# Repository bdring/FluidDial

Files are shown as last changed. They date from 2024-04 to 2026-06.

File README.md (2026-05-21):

# FluidDial: A Wired/Wireless CNC Pendant for FluidNC Firmware.

M5 Fluid DialCYD Dial Pendant

Wiki pages for more information: [M5 FluidDial Pendant (left image)](http://wiki.fluidnc.com/en/hardware/official/M5Dial_Pendant) and [CYD Dial Pendant (right image)](http://wiki.fluidnc.com/en/hardware/official/CYD_Dial_Pendant).

Both have similar functionality and similar cost, using different hardware.

## Overview

FluidDial supports two connection modes — **WiFi** and **Wired (UART)** — and is fully compatible with both the **M5Dial** and **CYD** pendant hardware.

In WiFi mode the pendant communicates with FluidNC over WebSockets on your local network. In Wired mode it uses the physical UART serial connection. The active mode is persisted across reboots and can be switched at any time from the Connection Settings screen.

### Features
- **DRO** — real-time X/Y/Z work coordinate display with configurable decimal places
- **Homing** — single-axis or full-machine homing with per-axis status feedback
- **Jogging** — multi-axis jog with encoder control, configurable step size, and one-tap axis zeroing
- **Probing** — Z-probe routine with configurable travel, feed rate, retract, and tool offset
- **SD File** — browse and run G-code files directly from the FluidNC SD card
- **Macros** — store and execute custom G-code macros from the pendant
- **Captive portal setup** — configure WiFi credentials directly from your phone or browser
- **Battery indicator** *(experimental)* — Supported in both M5Dial and CYD versions. *See [this sample project for CYD battery operation](https://github.com/figamore/FigDial)*

---

## Getting Started

### 1. Flash the Firmware

The easiest way to flash FluidDial is with the **[FluidDial Installer](https://installer.fluidnc.com)** — no build tools required. Connect your pendant via USB and follow the on-screen instructions.

### 2. First Boot — Choose Connection Mode

On first boot, the pendant displays a **Connection Mode** setup screen. Tap **Wired** or **WiFi** to choose your transport. This choice is saved and can be changed later from the Connection Settings screen.

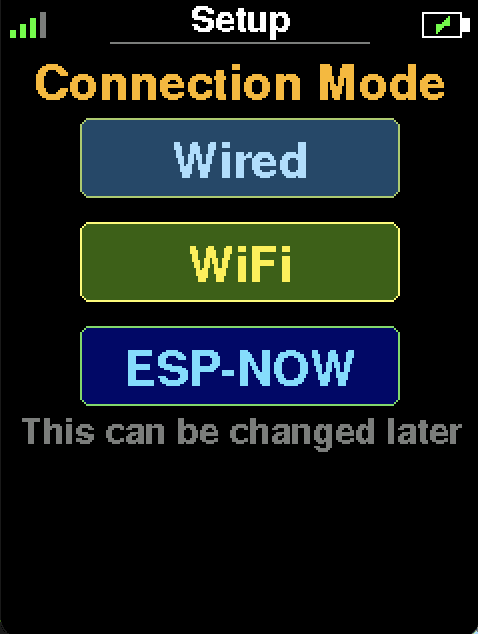
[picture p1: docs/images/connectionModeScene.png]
Connection Mode selection screen


### 3. WiFi Setup — Captive Portal

If you selected WiFi, the pendant starts an open access point named **"FluidDial"**.

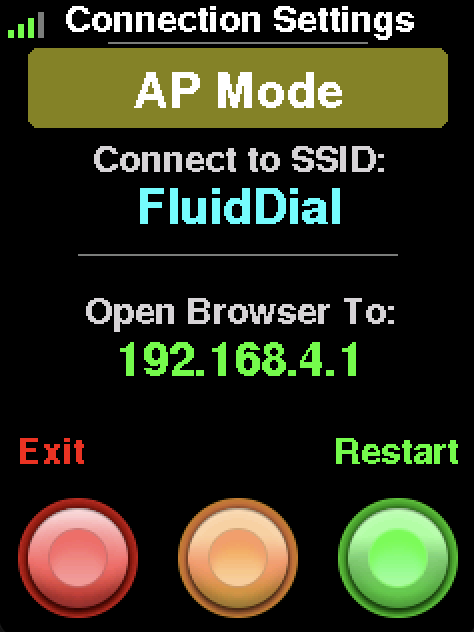
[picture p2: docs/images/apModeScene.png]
AP Mode screen showing SSID and browser address
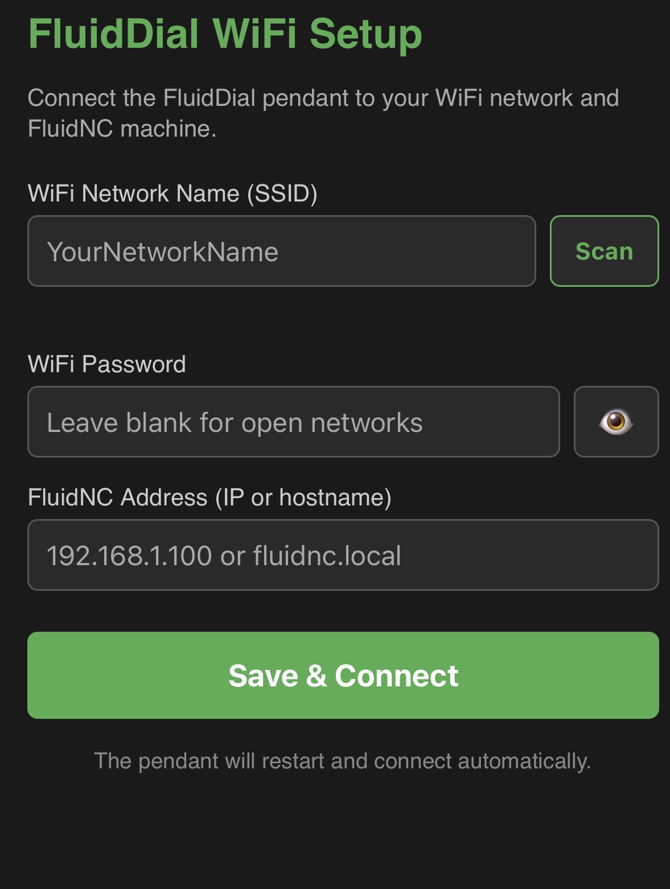
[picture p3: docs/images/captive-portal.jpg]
Captive portal — WiFi and FluidNC configuration form
 

1. Connect your phone or computer to the **FluidDial** Wi-Fi network
2. Open a browser and navigate to **192.168.4.1**
3. The captive portal will appear — scan for your home/shop network and select it
4. Enter your WiFi password and the hostname or IP address of your FluidNC machine
5. Tap **Save** — the pendant will restart, connect to your network, and establish a WebSocket connection to FluidNC

> **Tip:** If connecting to FluidNC's own default AP network, use these defaults:
>
> | Field | Value |
> |---|---|
> | SSID | FluidNC |
> | Password | 12345678 |
> | Hostname | 192.168.0.1 |

> **mDNS:** You can use a hostname like `fluidnc.local` instead of an IP address. The pendant resolves `.local` names automatically via mDNS.

### Connection Settings

The Connection Settings screen shows the current WiFi status and lets you switch modes or reconfigure.

**Connected:**

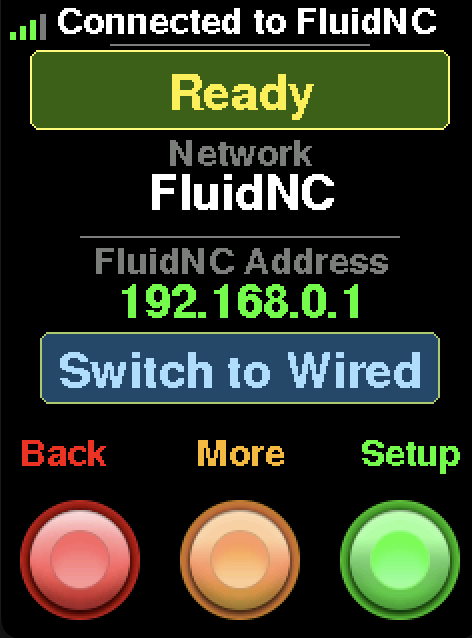
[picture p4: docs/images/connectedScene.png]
Connection settings — connected to FluidNC


Shows the connected network name, FluidNC address, and WebSocket status. Press **Setup** (green) to re-enter AP mode if you need to change credentials.

- **Back** (red) — return to the menu
- **More** (orange) — display orientation settings (CYD only), restart, and sleep (M5 dial only)
- **Switch to Wired / Switch to WiFi** button — toggle connection mode and restart

---

## Screens

### Main Menu

The main menu uses a circular pie layout. Each wedge navigates to a function.

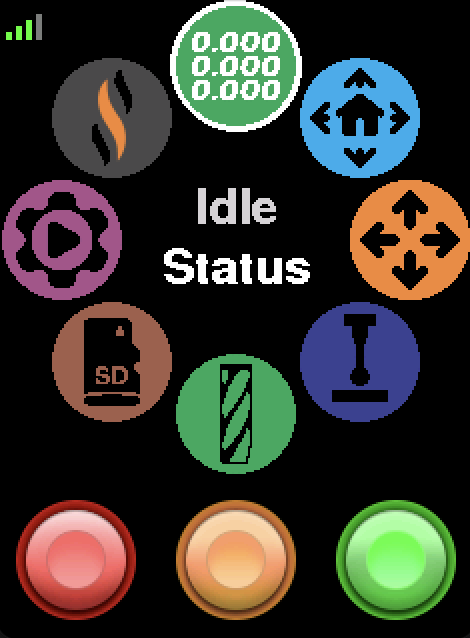
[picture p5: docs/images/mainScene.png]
Main menu pie layout


### Jog Scene

Displays X/Y/Z work coordinates. The active jog axis is highlighted in green. Rotate the encoder to jog. The red digit shows the currently editable decimal place.

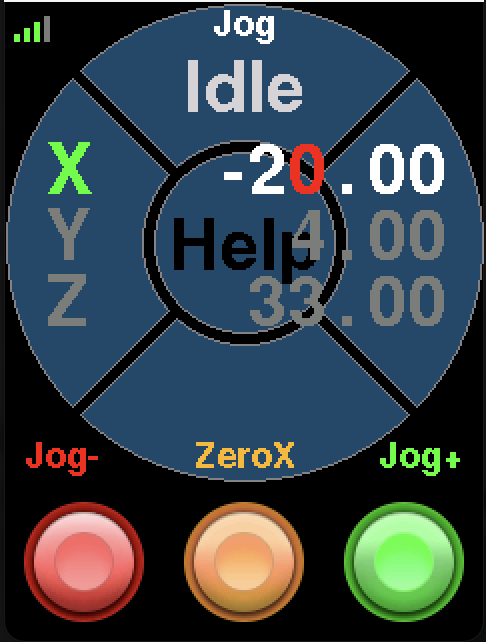
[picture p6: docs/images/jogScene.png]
Jog scene with X axis selected


### Probe Scene

Configurable Z-probe routine. All parameters are editable on-screen before running.

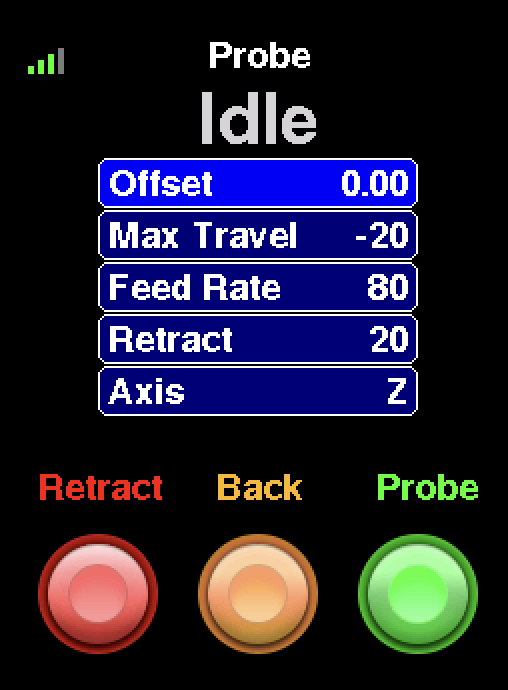
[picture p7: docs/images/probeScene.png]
Probe scene showing configurable parameters


| Parameter | Description |
|---|---|
| Offset | Tool length offset applied after probing |
| Max Travel | Maximum distance to travel looking for the probe |
| Feed Rate | Probing speed (mm/min) |
| Retract | Distance to retract after contact |
| Axis | Axis to probe (typically Z) |

---

## Building and Flashing from Source

Requires [PlatformIO](https://platformio.org/). Install the PlatformIO IDE extension for VS Code or use the CLI.

| Environment | Hardware |
|---|---|
| `m5dial` | M5Stack M5Dial |
| `cyddial` | CYD (2432S028) — auto-detects resistive or capacitive touch |

For example, to build and flash the CYD Dial:

```sh
pio run -e cyddial --target upload
```

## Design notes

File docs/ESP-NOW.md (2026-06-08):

# FluidDial ESP-NOW *(experimental)*

ESP-NOW is a new, optional connection mode for FluidDial that lets the pendant communicate directly with your FluidNC controller over a peer-to-peer encrypted radio link.

Pairing uses P-256 elliptic-curve key exchange and authenticated messages to establish a unique encrypted ESP-NOW key for each pendant and controller.

> **Flash the firmware:** Use the **[ESP-NOW Preview Installer](https://figamore.github.io/FluidDial)** to flash this experimental build onto your M5Dial or CYD pendant, as well as your FluidNC ESP32.

## Contents

- [Why ESP-NOW?](#why-esp-now)
- [Requirements](#requirements)
- [Pairing steps](#pairing-steps)
- [Pairing multiple machines](#pairing-multiple-machines)
- [Encryption and security](#encryption-and-security-overview)
- [Note on Pairing and WiFi mode](#esp-now-pairing-and-wifi-mode)
- [WiFi vs ESP-NOW](#wifi-vs-esp-now---which-should-i-choose)

---

## Why ESP-NOW?

This feature was added in response to user interest in a simpler, potentially more power-efficient wireless option:

- **Flexible pairing** - FluidNC can remember multiple pendants, and a pendant can save multiple machine profiles for quick switching.
- **User demand** - some users want wireless control without setting up a WiFi network or dealing with router configuration.
- **No router required** - the pendant talks directly to the FluidNC controller over a point-to-point encrypted radio link, so it works in any shop environment regardless of network availability.

---

## Requirements

### FluidNC

> **Note:** ESP-NOW requires a matching FluidNC build with ESP-NOW channel support. Because this has not yet been merged upstream, you must currently flash a temporary fork:
>
> **FluidNC fork:** [`figamore/FluidNC` - `feature/esp-now` branch](https://github.com/figamore/FluidNC/tree/feature/esp-now)
>
> This is temporary. Once the ESP-NOW channel implementation is accepted into the main FluidNC repository, a standard FluidNC release will work without any special build.

---

## Pairing steps

1. Flash the [ESP-NOW preview firmware](https://figamore.github.io/FluidDial) onto your pendant.
1. On first boot (or from Connection Settings), select **ESP-NOW** as the connection mode.
1. Leave FluidDial on the **ESP-NOW Pairing** screen.

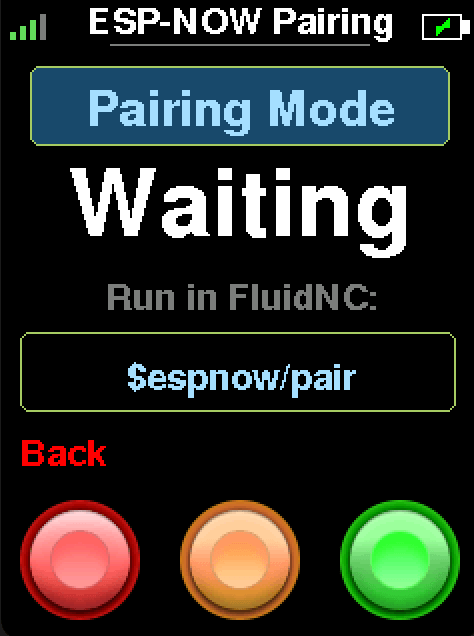
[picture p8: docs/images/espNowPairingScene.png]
FluidDial waiting for the FluidNC ESP-NOW pairing command


4. Open a pairing window on FluidNC using one of these methods:
   - In a FluidNC terminal, run `$espnow/pair`.
   - In [FigUI](https://github.com/figamore/gifui), open **Settings > ESP-NOW** and select **Pair Pendant**.
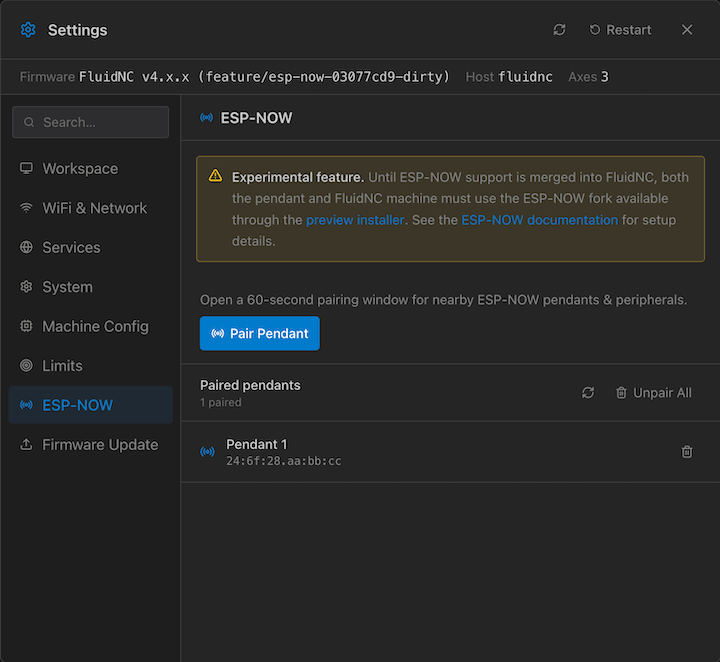
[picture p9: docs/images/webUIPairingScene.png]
FigUI ESP-NOW settings showing Pair Pendant and paired pendant controls
   
1. Wait for FluidDial to connect. Both devices save the pairing automatically.

---

## Pairing multiple machines

FluidDial can save profiles for multiple FluidNC machines. Open **Connection Settings > Machines** to select an existing machine, choose **Pair New** to add another one, or use **Forget** to delete the selected profile from the pendant.

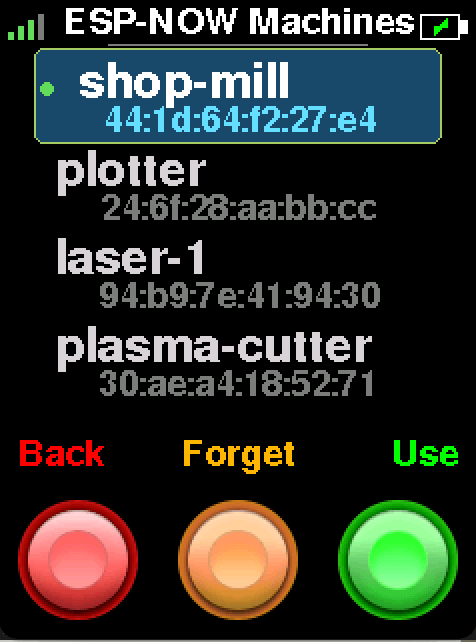
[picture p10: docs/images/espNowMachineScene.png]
FluidDial ESP-NOW machine list with Use and Forget controls


FluidNC also stores its own list of paired pendants. FigUI can list and remove individual pendants or **Unpair All** from **Settings > ESP-NOW**. The equivalent FluidNC terminal commands are:

- `$espnow/list` - list paired pendants and their numeric indexes.
- `$espnow/unpair=<index>` - remove one pendant using the index shown by `$espnow/list`.
- `$espnow/unpair=0` - remove all paired pendants.

Unpairing should be done on **both FluidDial and FluidNC**. Forget the machine on the pendant, then remove that pendant from FluidNC using FigUI or the ESP-NOW terminal commands. Removing only one side leaves a stale saved profile on the other device.

---

## Encryption and security overview

ESP-NOW traffic is not just accepted from any nearby device. FluidNC keeps a saved list of paired pendant MAC addresses, and FluidDial keeps saved machine profiles. A pendant must complete pairing before FluidNC will accept it as a trusted peer.

Pairing is opened only temporarily, either from the FluidNC terminal or from FigUI. During pairing, FluidDial and FluidNC exchange fresh public keys and derive a shared per-pair key. Pairing confirmation packets include HMAC-SHA256 authentication tags, so a random device cannot complete pairing just by copying the packet format.

After pairing, the devices register each other as encrypted ESP-NOW peers using an LMK. ESP-NOW's encrypted peer mode uses the ESP32 WiFi/ESP-NOW security layer for over-the-air encryption.

FluidDial and FluidNC also add a small anti-replay layer above ESP-NOW. Keepalive, realtime, and data packets carry nonce/counter values so stale packets cannot simply be replayed later as valid control traffic.

This protects against casual or accidental cross-connection, packet sniffing, and simple replay attempts.

---

### Note on ESP-NOW Pairing and WiFi Mode

ESP-NOW pairings are tied to the WiFi mode used during pairing because AP and STA modes use different MAC addresses. A pendant paired while FluidNC is in AP mode must be re-paired after switching to STA mode, and vice versa.

---

## WiFi vs ESP-NOW - which should I choose?

| | WiFi | ESP-NOW |
|---|---|---|
| **Router required** | Yes | No |
| **Range** | Limited by your network | ~100 m line-of-sight (ESP32 radio) |
| **Setup complexity** | Moderate (captive portal) | Low (one-command or FigUI pairing) |
| **Network interference** | Shares band with other devices | Dedicated peer channel |
| **Power consumption** | Higher (full WiFi stack) | Potentially lower, but not by much |

**Choose WiFi if:**
- You already have a reliable network in your shop and want the pendant on it alongside other devices.
- You use FluidNC's built-in web UI or other networked tools alongside the pendant.

**Choose ESP-NOW if:**
- You have no router near your machine, or want to avoid network setup entirely.
- You are running the pendant on battery and want to explore lower power consumption.
- You want the simplest possible wireless setup with minimal configuration.
- You want to control multiple machines with a single pendant.

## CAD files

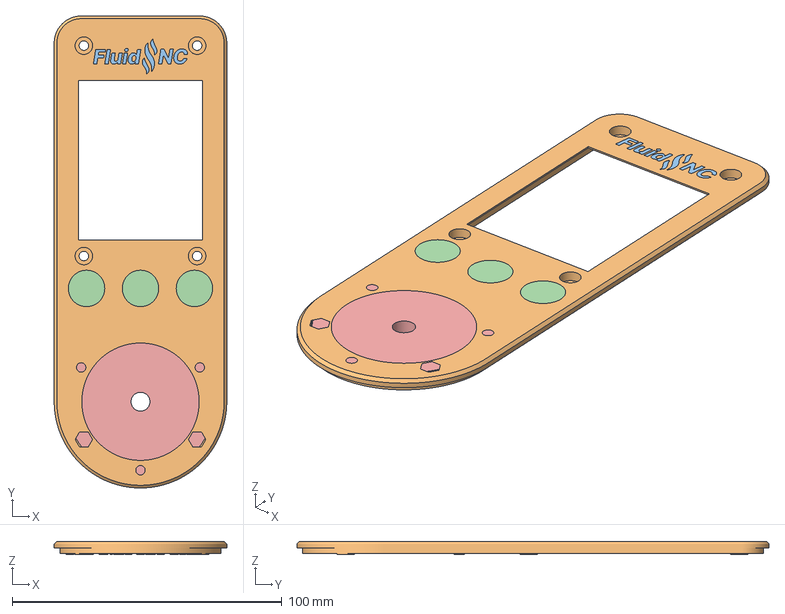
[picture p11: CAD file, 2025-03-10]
part_files/CYD_Dial_JC2432W328C_top.3mf
64.0 x 175.0 x 5.00 mm

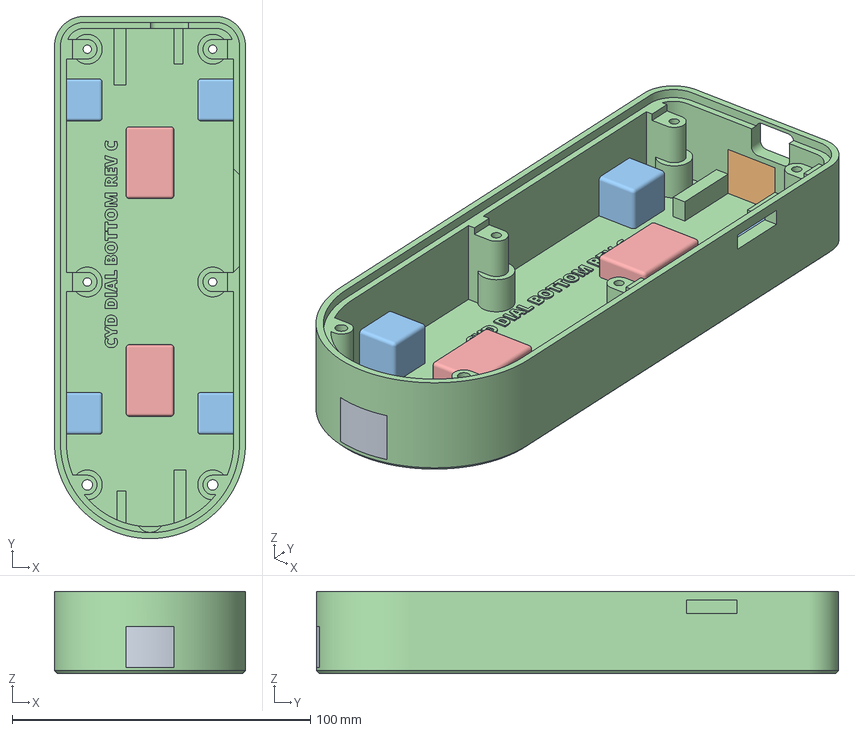
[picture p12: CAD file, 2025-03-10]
part_files/CYD_Dial_JC2432W328C_bottom.3mf
64.0 x 175.0 x 27.5 mm

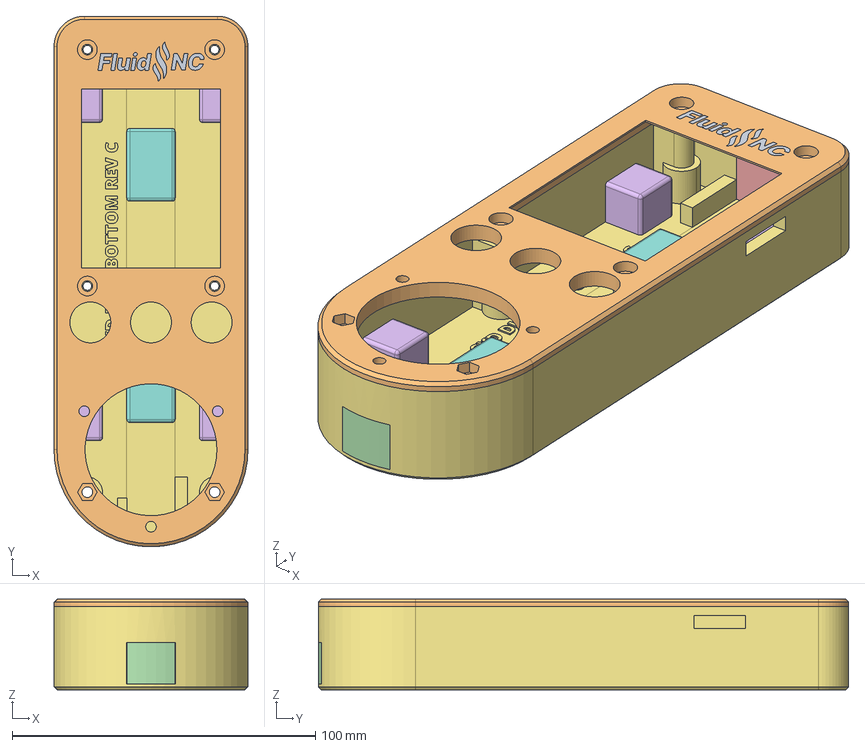
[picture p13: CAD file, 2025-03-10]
part_files/CYD_Dial_JC2432W328C.FCStd
64.0 x 175.0 x 30.0 mm
FluidNCLogo
Top With FluidNC
CYD DIAL TOP REV C
Bottom RJ12 Filler rounded side
Bottom RJ12 Filler squared side
Bottom Magnet Holder
Bottom Rev C
Hook Cover

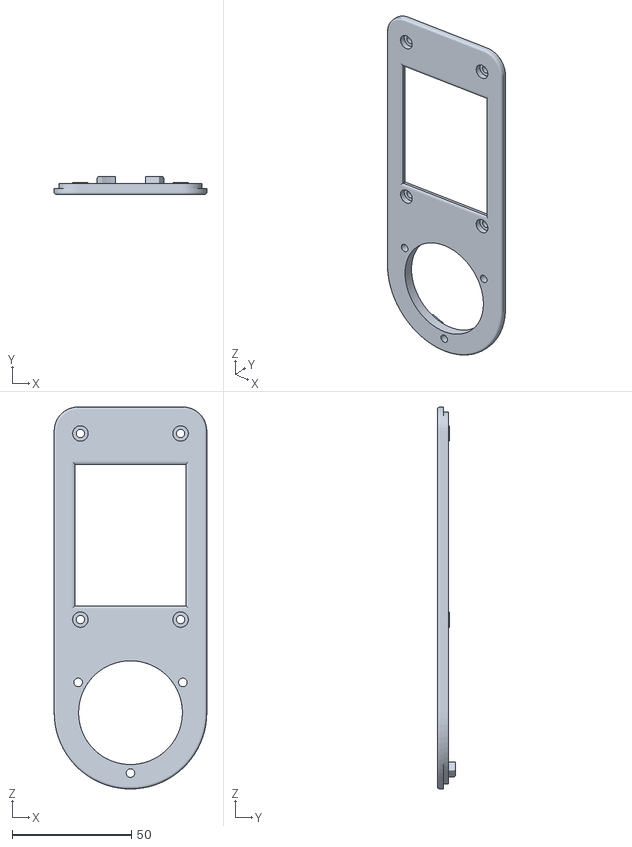
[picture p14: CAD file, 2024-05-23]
part_files/CYD_Dial_Top.stl
64.0 x 7.60 x 160.1

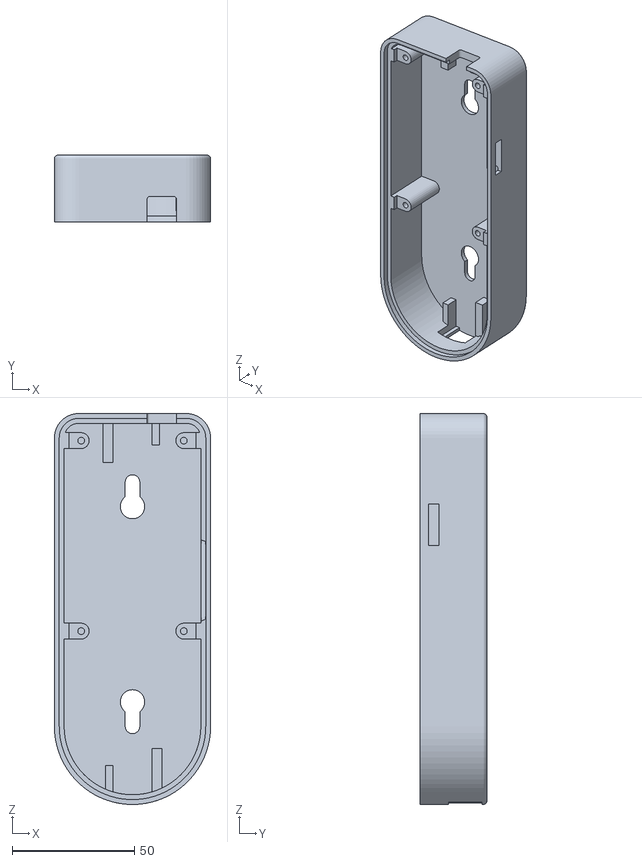
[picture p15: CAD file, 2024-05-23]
part_files/CYD_Dial_Bottom.stl
64.0 x 27.4 x 160.1

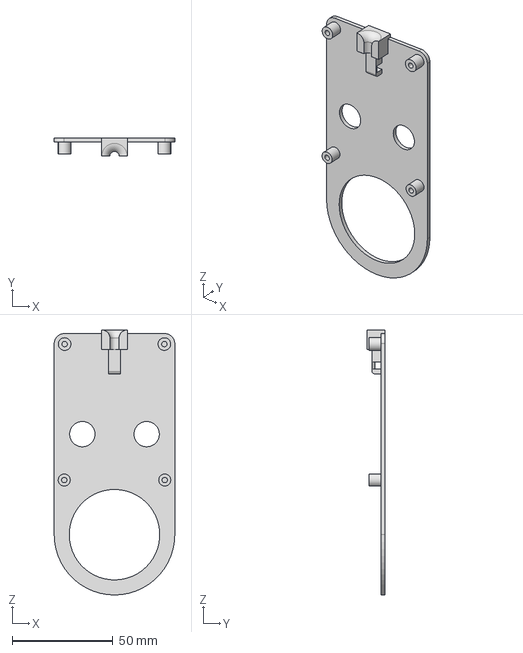
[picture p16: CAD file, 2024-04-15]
part_files/FluidDialTop.step
60.0 x 9.00 x 131.8 mm

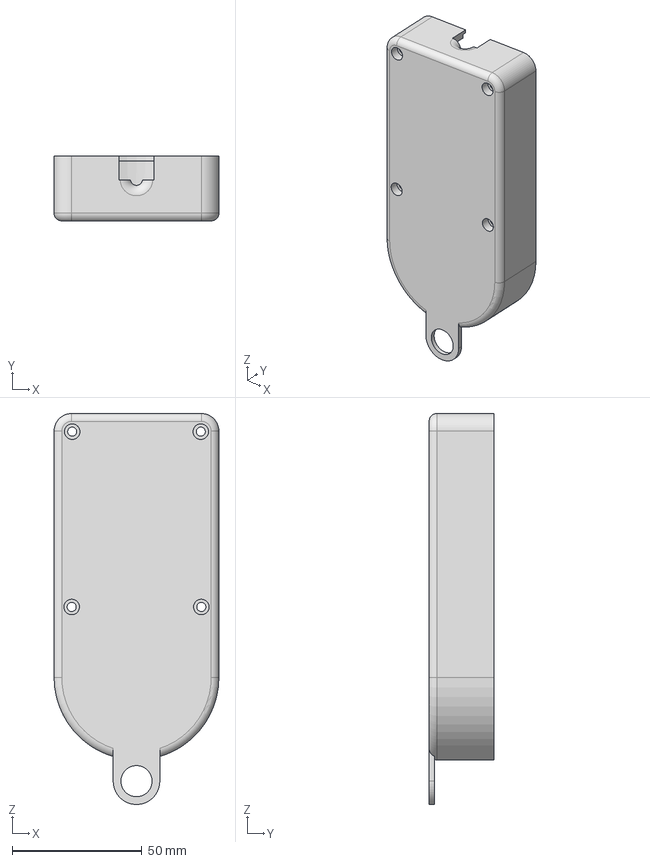
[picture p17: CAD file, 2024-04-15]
part_files/FluidDialBottom.step
63.6 x 25.0 x 150.8 mm

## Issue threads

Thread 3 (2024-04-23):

Dial disconnects ~30 seconds after initial startup

zjt48162, 2024-04-23:
The dial successfully connects a few seconds after powering on the controller, and I'm able to control the machine briefly. But it won't stay connected and reverts to the N/C state after a short period of time, even with zero motion. Controller is on the latest release (3.7.16), and dial firmware was built today.

Tx and Rx lines measure at 0.6 ohms each; wiring is not damaged.

I can provide logs, but I'll need instructions on how to get them. Thanks.

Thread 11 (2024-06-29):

Support CYD with capacitive touch screen

michaelslobodskih, 2024-06-29:
Tried to upload code to cyd with capacitive touch screen, but with no luck. Screen is black
here is example of board https://aliexpress.ru/item/1005006729707613.html
I think its better than resistive ts

MitchBradley, 2024-06-29:
Send me one and I will figure out what is wrong.

kiwiwarwick, 2024-08-14:
Hello, I've just uploaded the CYD branch onto a CYD screen, it uploaded fine, but the screen is very dim, I can only just make out that there is items displaying. Any ideas?

MitchBradley, 2024-08-14:
I haven't tried this but it looks like it might be relevant https://github.com/hexeguitar/ESP32_TFT_PIO?tab=readme-ov-file#4-free-up-the-gpio21

Golabstech, 2024-11-10:
I'm having the same problem. I think the capacitive display driver of this screen is different from the main topic, and I leave the relevant links. If you are interested or can tell me how to do it, I can try to do it. @MitchBradley

Hardware: Guition ESP32 4M FLASH 2.8-inch 240*320
Screen driver and touch screen: ST7789V3+CTC2.8TN(PH028NA-01A)
Related documentation and demo files: https://drive.google.com/drive/folders/1_jopr5ylYFRVXi-l7rBj2bIgqWn8grnV?usp=sharing
Aliexpress: https://aliexpi.com/pJJ8

MitchBradley, 2024-11-10:
If you can't do it without me telling you how, it would be easier for me to just do it myself.  I said I would do that if someone would send me one, and nobody took me up on it, so I can only conclude that my time is not worth $10.

Golabstech, 2024-11-10:
@MitchBradley I missed this message of yours. This is what being an open source developer should be like. While you want everyone to do their part, those who use what you compile always want more. Of course I can send you one. On profile Can I reach you via your email address in your profile?

Golabstech, 2024-11-10:
@MitchBradley I missed this message of yours. This is what being an open source developer should be like. While you want everyone to do their part, those who use what you compile always want more. Of course I can send you one. On profile Can I reach you via your email address in your profile?

MitchBradley, 2024-11-14:
> @MitchBradley I missed this message of yours. This is what being an open source developer should be like. While you want everyone to do their part, those who use what you compile always want more. Of course I can send you one.

DM me on Discord and I will give you the address.

trashypopashy, 2025-03-06:
Are there news on this? Is the capacitive CYD fully compatible, now?

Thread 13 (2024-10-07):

error compiling cyd

liwajaya, 2024-10-07:
please guide me i try to compile but always error

`note:   initializing argument 3 of 'esp_err_t nvs_get_i32(nvs_handle_t, const char*, int32_t*)'
  375 | esp_err_t nvs_get_i32 (nvs_handle_t handle, const char* key, int32_t* out_value);
      |                                                              ~~~~~~~~~^~~~~~~~~
*** [.pio\build\cyd\src\Hardware2432.cpp.o] Error 1
============================================ [FAILED] Took 36.20 seconds ============================================`

thanks

MitchBradley, 2024-10-07:
There is not nearly enough context in this report to solve the problem.  The final fragment of the error message does not provide enough information.

liwajaya, 2024-10-09:
mr @MitchBradley
Thank you for your quick response, this is the error code that I copied. Please help me where the error occurred.

`Executing task: C:\Users\liwajaya\.platformio\penv\Scripts\platformio.exe run --environment cyd

Processing cyd (platform: espressif32; board: esp32dev; framework: arduino)
------------------------------------------------------------------------------------------------------------------------------Verbose mode can be enabled via `-v, --verbose` option
CONFIGURATION: https://docs.platformio.org/page/boards/espressif32/esp32dev.html
PLATFORM: Espressif 32 (51.3.4) > Espressif ESP32 Dev Module
HARDWARE: ESP32 240MHz, 320KB RAM, 4MB Flash
DEBUG: Current (cmsis-dap) External (cmsis-dap, esp-bridge, esp-prog, iot-bus-jtag, jlink, minimodule, olimex-arm-usb-ocd, olimex-arm-usb-ocd-h, olimex-arm-usb-tiny-h, olimex-jtag-tiny, tumpa)
PACKAGES:
 - framework-arduinoespressif32 @ 3.20017.0 (2.0.17)
 - framework-arduinoespressif32-libs @ 5.1.0+sha.b6b4727c58
 - tool-esptoolpy @ 4.7.5
 - tool-mklittlefs @ 3.2.0
 - tool-riscv32-esp-elf-gdb @ 11.2.0+20220823
 - tool-xtensa-esp-elf-gdb @ 11.2.0+20230208
 - toolchain-xtensa-esp32 @ 12.2.0+20230208
LDF: Library Dependency Finder -> https://bit.ly/configure-pio-ldf
LDF Modes: Finder ~ chain, Compatibility ~ soft
Found 44 compatible libraries
Scanning dependencies...
Dependency Graph
|-- JsonStreamingParser @ 0.0.0+char-1.0.2.sha.846bc19
|-- GrblParser @ 1.0.0+sha.9108f54
|-- LovyanGFX @ 1.1.16
|-- LittleFS @ 2.0.0
Building in release mode
Compiling .pio\build\cyd\src\Hardware2432.cpp.o
Compiling .pio\build\cyd\src\Menu.cpp.o
In file included from C:/Users/liwajaya/.platformio/packages/framework-arduinoespressif32/tools/sdk/esp32/include/freertos/include/freertos/portable.h:51,
                 from C:/Users/liwajaya/.platformio/packages/framework-arduinoespressif32/tools/sdk/esp32/include/freertos/include/freertos/FreeRTOS.h:63,
                 from C:/Users/liwajaya/.platformio/packages/framework-arduinoespressif32/cores/esp32/Arduino.h:33,
                 from src/System.h:10,
                 from src/Hardware2432.cpp:6:
C:/Users/liwajaya/.platformio/packages/framework-arduinoespressif32/tools/sdk/esp32/include/freertos/port/xtensa/include/freertos/portmacro.h:613:48: warning: ignoring attribute 'section (".iram1.24")' because it conflicts with previous 'section (".iram1.22")' [-Wattributes]
  613 | static inline bool IRAM_ATTR xPortCanYield(void)
      |                                                ^
In file included from C:/Users/liwajaya/.platformio/packages/framework-arduinoespressif32/tools/sdk/esp32/include/freertos/include/freertos/portable.h:51,
                 from C:/Users/liwajaya/.platformio/packages/framework-arduinoespressif32/tools/sdk/esp32/include/freertos/include/freertos/FreeRTOS.h:63,
                 from C:/Users/liwajaya/.platformio/packages/framework-arduinoespressif32/cores/esp32/Arduino.h:33,
                 from src/System.h:10,
                 from src/Text.h:7,
                 from src/Drawing.h:8,
                 from src/Scene.h:7,
                 from src/Menu.h:6,
                 from src/Menu.cpp:4:
C:/Users/liwajaya/.platformio/packages/framework-arduinoespressif32/tools/sdk/esp32/include/freertos/port/xtensa/include/freertos/portmacro.h:613:48: warning: ignoring attribute 'section (".iram1.24")' because it conflicts with previous 'section (".iram1.22")' [-Wattributes]
  613 | static inline bool IRAM_ATTR xPortCanYield(void)
      |                                                ^
C:/Users/liwajaya/.platformio/packages/framework-arduinoespressif32/tools/sdk/esp32/include/freertos/port/xtensa/include/freertos/portmacro.h:343:30: note: previous declaration here
  343 | static inline bool IRAM_ATTR xPortCanYield(void);
      |                              ^~~~~~~~~~~~~
C:/Users/liwajaya/.platformio/packages/framework-arduinoespressif32/tools/sdk/esp32/include/freertos/port/xtensa/include/freertos/portmacro.h:632:55: warning: ignoring attribute 'section (".iram1.25")' because it conflicts with previous 'section (".iram1.23")' [-Wattributes]
  632 | static inline BaseType_t IRAM_ATTR xPortGetCoreID(void)
      |                                                       ^
C:/Users/liwajaya/.platformio/packages/framework-arduinoespressif32/tools/sdk/esp32/include/freertos/port/xtensa/include/freertos/portmacro.h:385:36: note: previous declaration here
  385 | static inline BaseType_t IRAM_ATTR xPortGetCoreID(void);
      |                                    ^~~~~~~~~~~~~~
C:/Users/liwajaya/.platformio/packages/framework-arduinoespressif32/tools/sdk/esp32/include/freertos/port/xtensa/include/freertos/portmacro.h:343:30: note: previous declaration here
  343 | static inline bool IRAM_ATTR xPortCanYield(void);
      |                              ^~~~~~~~~~~~~
C:/Users/liwajaya/.platformio/packages/framework-arduinoespressif32/tools/sdk/esp32/include/freertos/port/xtensa/include/freertos/portmacro.h:632:55: warning: ignoring attribute 'section (".iram1.25")' because it conflicts with previous 'section (".iram1.23")' [-Wattributes]
  632 | static inline BaseType_t IRAM_ATTR xPortGetCoreID(void)
      |                                                       ^
C:/Users/liwajaya/.platformio/packages/framework-arduinoespressif32/tools/sdk/esp32/include/freertos/port/xtensa/include/freertos/portmacro.h:385:36: note: previous declaration here
  385 | static inline BaseType_t IRAM_ATTR xPortGetCoreID(void);
      |                                    ^~~~~~~~~~~~~~
src/Hardware2432.cpp: In function 'void init_hardware()':
src/Hardware2432.cpp:67:35: error: invalid conversion from 'int*' to 'int32_t*' {aka 'long int*'} [-fpermissive]
   67 |     nvs_get_i32(hw_nvs, "layout", &layout_num);
      |                                   ^~~~~~~~~~~
      |                                   |
      |                                   int*
In file included from C:/Users/liwajaya/.platformio/packages/framework-arduinoespressif32/tools/sdk/esp32/include/nvs_flash/include/nvs_flash.h:21,
                 from src/nvs.h:2,
                 from .pio/libdeps/cyd/LovyanGFX-1.1.16/src/lgfx/v1_autodetect/LGFX_AutoDetect_ESP32_all.hpp:23,
                 from .pio/libdeps/cyd/LovyanGFX-1.1.16/src/lgfx/v1_autodetect/common.hpp:30,
                 from .pio/libdeps/cyd/LovyanGFX-1.1.16/src/LGFX_AUTODETECT.hpp:20,
                 from src/Hardware2432.cpp:7:
C:/Users/liwajaya/.platformio/packages/framework-arduinoespressif32/tools/sdk/esp32/include/nvs_flash/include/nvs.h:375:71: note:   initializing argument 3 of 'esp_err_t nvs_get_i32(nvs_handle_t, const char*, int32_t*)'
  375 | esp_err_t nvs_get_i32 (nvs_handle_t handle, const char* key, int32_t* out_value);
      |                                                              ~~~~~~~~~^~~~~~~~~
*** [.pio\build\cyd\src\Hardware2432.cpp.o] Error 1
================================================ [FAILED] Took 348.07 seconds ================================================
 *  The terminal process "C:\Users\liwajaya\.platformio\penv\Scripts\platformio.exe 'run', '--environment', 'cyd'" terminated with exit code: 1.
 *  Terminal will be reused by tasks, press any key to close it.
`

MitchBradley, 2024-11-10:
The error output above shows:
```
toolchain-xtensa-esp32 @ 12.2.0+20230208
```
My compilation setup is using toolchain-xtensa-esp32 @ 8.4.0+2021r2-patch5, because of this clause in <HOMEDIR>/.platformio/platforms/espressif32/platform.json, which is at version 6.9.0:
```
  "packages": {
    "toolchain-xtensa-esp32": {
      "type": "toolchain",
      "owner": "espressif",
      "version": "8.4.0+2021r2-patch5"
    },
```
I suspect that a different version of the espressif32 package somehow got installed on your system.  It is possible to clear out existing package versions by executing
```
pio pkg uninstall --package espressif32
```
Then when you run the pio build again, it will reinstall the package, hopefully at the correct version.  When I did that just now, it got the right version and the cyd compilation succeeded.

rgriebl, 2025-04-04:
Please close: this is fixed by #26

Closed 2025-04-04.

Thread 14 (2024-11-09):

Dial froze in Macros menu, and now appears to be dead

shampeon, 2024-11-09:
FluidNC 3.7.18
Latest master from FluidDial

After checking and double-checking I got all the pins/cables wired correctly, I got the Dial working this afternoon, and was able to home and jog.

I was checking out the various menus, and selected Macros. I don't have any macros defined in FluidNC. At that point, the Dial froze, and I was unable to exit the Macros menu. Meaning, the M5 bezel button, touchscreen, or physical buttons didn't do anything. The touchscreen was illuminated but frozen on "Reading Macros". I unplugged the Dial, and then plugged it back in to see if it would reset. Now the Dial won't boot, and is unresponsive when powered either through the cable or USB-C.

I can see that the Dial is receiving power, as there's a red light visible within the Dial when powered by the 2 pin cable or USB-C.

I tried plugging it into my desktop to reflash, but the port doesn't come up.

~~~yaml
uart1:
  txd_pin: gpio.17
  rxd_pin: gpio.16
  rts_pin: NO_PIN
  cts_pin: NO_PIN
  baud: 1000000
  mode: 8N1

uart_channel1:
  report_interval_ms: 75
  uart_num: 1
~~~

shampeon, 2024-11-09:
Just removed the Stamp S3, and plugged into USB-C it's still unresponsive, and now hot to the touch.

shampeon, 2024-11-09:
...and my FluidNC controller is apparently dead. What in the heck happened?

I buzzed out the wiring to make sure there were no shorts, and tested it disconnected from the M5 Dial to make sure it was getting 24V on the right cables.
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

MitchBradley, 2024-11-09:
My guess is an intermittent ground connection that resulting in the 24V supply returning through the rx/tx lines.

shampeon, 2024-11-10:
Is that something that could have been prevented with an optoisolator board?

MitchBradley, 2024-11-10:
optical isolation is one of many ways to prevent it.

shampeon, 2024-11-10:
I was pretty careful with this build (e.g. I knew that FluidNC tx <-> Dial rx, and Dial tx <-> rx, and getting this wrong could be catastrophic, so I verified everything with a multimeter), highlighted in the caveats in the docs, but techniques to isolate the tx/rx would have been good information to have before even trying this. My controller is cooked, as is my dial.

MitchBradley, 2024-11-10:
> techniques to isolate the tx/rx would have been good information to have before even trying this. My controller is cooked, as is my dial.

Responses to implied criticism:
1. This is a DIY thing, early in its lifetime.  We didn't realize it was going to be so fragile until people started blowing up things due to miswiring.  Hindsight is 20/20
2. Having learned some of the pitfalls, Bart now sells a connection kit with protection and we do not recommend or support not using it.  Early on, I did my own version of a connection kit but abandoned it because I realized that finishing it and supporting it would be a money-losing proposition for me as, unlike Bart, I am not set up for selling hardware.  Some of the concepts of my kit made it into Bart's design.
3. I have never blown up anything despite having made 4 dials.  Perhaps it is because I have always powered mine from 5V instead of higher voltages.  The only way to get 5V into an M5 Dial is via the USB-C connector which is a bit more trouble, DIY-wise, than the screw terminal connector.  I made a PCB with a USB-C male and other relevant connectors, but it is possible to buy USB-C male breakouts for point to point wiring.
4. You are welcome to edit the wiki to add additional warnings or instructional material about isolation techniques and their tradeoffs, limitations, and implementation methods.  I don't feel inclined to do so, preferring to waste my time on other aspects of this extensive project that generates an extraordinary number of requests for support, debugging of hardware that we do neither control nor benefit from, and new features for one-off use cases.  Meanwhile the donation rate is sufficient to buy one breakfast per month at the local diner.

shampeon, 2024-11-10:
Mitch, I did volunteer my time to try to improve the FluidNC wiki docs earlier this year, until it was made pretty clear by you that I was wasting your time when I tried to get clarification on info in the docs that you understood but I didn't. That is an impossible set of conflicting attitudes to resolve--better docs means fewer support requests and more time for development on your part--so I stepped away, as you're not the only one with time scarcity.

I don't know if this will mean anything to you, as you have already decided that I'm being unreasonable, but on point 4, if this was knowledge that I possessed, would I have had the problem I encountered? Where would I have reasonably found this information when I decided to make one of these pendants? If you read the wiki page as it exists right now, would you conclude that the only recommended way of adding this pendant is to purchase one of Bart's connection kits?

Anyway, the issue appears to not be a software problem, so I'll close this, and wish you well in growing your community.

Closed 2024-11-10.

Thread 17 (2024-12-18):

Screen orientation

banana-legs, 2024-12-18:
For those who use the CYD units 'upside down' with the cable connector and dial oriented below the screen, and with the latest code updates now changed so that some units can control screen brightness when the dial is turned on the 'about screen', try setting
layout_num = 4;
on line 73 of Hardware2432.cpp

guillaume-rico, 2025-02-27:
The ability to rotate the screen is described in the Wiki.
Unfortunately it was removed in the commit of December 14, 2024

To reinstate this functionality, you can add
next_layout(delta);
At the beginning of the AboutScene::onEncoder function in the AboutScene.cpp file (after line 52)

dJOS1475, 2025-04-13:
@guillaume-rico sorry for the stupid question, Im not a dev - is this what you mean?

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

Another question, how do I get rid of the OSD buttons (Im using physical buttons)?

dJOS1475, 2025-04-13:
I think I figured it out what you meant, however it doesnt work for me:

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

dJOS1475, 2025-04-13:
Ok, what worked was @banana-legs solution, but it's now at a different location:

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

@guillaume-rico is there a simple method to remove the OSD buttons and reclaim that space?

fcobcn, 2025-10-04:
I'm also looking for a method to remove the buttons from the screen. @dJOS1475 did you find a way?

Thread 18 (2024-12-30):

Laser menu

ennio64, 2024-12-30:
It is possible to add a menu for lasers with x, y and a (rotation) axes.
Thanks.

MitchBradley, 2024-12-30:
The code is open source so you can add any scenes that you want.  Are you really asking if someone is willing to add the menu for you, for free?

ennio64, 2024-12-30:
Not for me, for all.
Considering that fluidnc firmware serves both CNC and laser machines it would make the project more complete.

MitchBradley, 2024-12-30:
I will add the feature if we get $300 of new FluidNC sponsors who indicate that they want that particular feature.  If the feature is truly beneficial to "all", surely it will be possible to get that much sponsorship aggregated across a group of people.  That amount will not pay for my actual development time to design, code, test and document the feature but I am willing to do it for that amount nevertheless.

I expect that, even with an XYA menu, the pendant would not be great for lasers, since it does not have a fire button or a framing button.

Some stats: There were 13000 users of the WebInstaller last year.  The total number of release downloads across all releases is about 55,000, and each new release is downloaded between 1500 and 2500 times, independent of WebInstaller uses.  The FluidNC Discord server has 3700 members.  The number of sponsors is 116, many of whom contributed only $5.  The FluidNC developers together have spent an estimated 4000 hours developing and supporting FluidNC and the pendants.  The market price for developers of that caliber exceeds $100/hour.  The existing hardware page lists 35 controller boards that support FluidNC.  Several of them are third-party commercial products, and very few of their vendors contribute to the FluidNC development, despite the fact that we answer questions from their customers.

So I conclude that the project is fairly "complete", and of the "all", most are benefiting from the work of the developers without giving back.  We are getting tired of people asking for new features without offering to contribute anything substantial.

Closed 2025-01-08.

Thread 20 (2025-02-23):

Wrong wiring instruction in the wiki for capacitive CYD

jseo901, 2025-02-23:
I found that the encoder A connection picture in the CYD wiki for the capacitive CYD is wrong.  For encoder A should be GPIO 16 not 22

MitchBradley, 2025-02-27:
I changed my mind about the best wiring.  Further wiring options might be forthcoming after a series of experiments I am planning.

Closed 2025-02-27.

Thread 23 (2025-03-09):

Compatiblility with MKS DLC32

trashypopashy, 2025-03-09:
Is the FluidDial compatible with the MKS DLC32 (V2.1 or MAX)?

bdring, 2025-03-09:
MAX (wrong ESP32 type) is not compatible with FluidNC.  The FluidDial can be be hacked onto the MKS, but it is not recommended. Wiring issues can destroy both the controller and the dial. We recommend using the connection kits and compatible controllers.

http://wiki.fluidnc.com/en/hardware/official/M5Dial_Pendant#rj12-connectors

trashypopashy, 2025-03-11:
Will the MAX be supported someday or is it impossible to get fluidnc running on this specific ESP32 type?

I saw [this](https://oshwlab.com/bdring/rodent-rj12-pendant-adapter) and am thinking of using it on my CNC Mill which I bulid some years ago with the MKS DLC32 (not Max), which works almost okay with the MKS-Firmware. I am thinking of getting a DLC32 Max for it or staying with the DLC32 and would love to have a Pendant Dial... Is you adapter board also compatible with the DLC32 (not Max)? At least it hat I2C...

MitchBradley, 2025-03-12:
There has been a lot of work on ESP32-S3, but so far we haven't released anything.  It is going to be a substantial support burden and we are already overwhelmed with people wanting new stuff and handholding with old stuff.  DLC32 is especially troublesome because it is cheap, so lots of people want to use it and ask for help, but MKS does not support the project in any way.  So we effectively act as an unpaid support resource for a third party.

trashypopashy, 2025-03-13:
Thanks for Your overwhelming work! I'm going to buy a dedicated FluidNC-Board.

Is it possible to use a FluidDial Pendant (with CYD) and a tiny OLED in the Board at the same time?

AttilaZee, 2025-04-02:
If anyone is still interested in this topic, I managed to connect a CYD FluidDial to the MKS DLC32 v2.1.

After flashing FluidNC on the MKS DLC32, the EXP1/EXP2 display connectors and the corresponding IO pins routed to EXP1/EXP2 are free to be used for other purposes.
So I connected 5V and GND on EXP1, and IO23 and IO19 on EXP2 to the CYD (2432S028R).

Here is the connection between the pins on the MKS EXP1/EXP2 port and FluidDial highlighted.

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

Then I just added the following lines to the FluidNC configuration file (config.yaml or whatever the filename of you config file is):
```
uart1:
 txd_pin: gpio.23
 rxd_pin: gpio.19
 rts_pin: NO_PIN
 cts_pin: NO_PIN
 baud: 1000000
 mode: 8N1

uart_channel1:
 report_interval_ms: 75
 uart_num: 1
```

I haven't done any exhaustive tests yet but I was able to move around the tool on my CNC with FluidDial.

I only had some struggle to make the FluildDial firmware work with the CYD (ESP32-2432S028R), but that's a different story and has nothing to do with this topic.

MitchBradley, 2025-04-02:
Please add that info to the wiki.  People are unlikely to find it here.

AttilaZee, 2025-04-03:
Do you mean the FluidDial wiki? Sure, I can do. I just wasn't expecting that this info is worth a wiki entry :-)

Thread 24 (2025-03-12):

Wiki : Error in the wiring diagram?

guillaume-rico, 2025-03-12:
I think there is an error in the wiring diagram of the following two versions (in the Wiki) :
 * No-Debug Wiring with Handwheel and Buttons
 * No-Debug Wiring with Rotary Encoder and Buttons

FNC_5V is connected to pin 2 of the RJ12. But this pin is powered by VMot.
I think FNC_5V should be connected to pin 3 of the RJ12 connector.

(This is what is done for the other two wirings:
* Wiring for USB Debugging
* Resistive CYD )

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

guillaume-rico, 2025-03-15:
Image corrected for "Capacitive CYD Wiring with Handwheel and Buttons"

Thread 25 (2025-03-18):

Enable button

trashypopashy, 2025-03-18:
Hello again,

is there a way to switch the display touch function off with a gpio?

I want to build the CYD PendantDial and want to put a momentary switch in series to GND for the handwheel and the three buttons, so it is noch possble to accidentially move the CNC-Mill. This is an easy task. But when it comes to the display, things get complicated. Do you have any sugestions, how to disable/enable the touch input by an external button? Would also cut a line on the PCB and solder wires from there to the button.

Thanks again for your great work on FluidNC!

Closed 2025-03-28.

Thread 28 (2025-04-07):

Wrong connector type for M5Dial listed

jhitesma, 2025-04-07:
I tried to edit the wiki but got an error trying to create an account.  So reporting here.

The page: http://wiki.fluidnc.com/en/hardware/official/M5Dial_Pendant

It states:

> (I think these are JST-PH connectors with a 2 mm pitch. Note: you'll need to cut the locking tabs off the white connectors to get them to plug in.)

The connectors on the m5dial are NOT JST-PH with a 2mm pitch.  They are grove connectors which are HY2.0 which are simlar to JST-PH but not quite the same.   I had some JST-PH 2.0's on hand so thought I could build up a dial without ordering anything other than the dial itself...only to find that JST-PH actually won't fit and I had to order some of the grove HY connectors instead.  (Bare crimp your own HY connectors seem to be tricky to find outside of Asia - but the pigtails are easily found.)

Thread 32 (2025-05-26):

Getting blank white screen after uploading the code.

pranaysawarkar, 2025-05-26:
I am trying to upload the code to my ESP32-2432S028R CYD, but I am getting white screen after successfully uploading the code. I am using cyd_resistive build to upload.
Can you help me to solve this issue please..

pranaysawarkar, 2025-05-27:
Hello Mitch,

Thank you for the quick reply — I really appreciate your work and the effort you’ve put into the FluidDial project!
I wanted to follow up regarding the white screen issue I mentioned earlier.

I tried flashing the latest precompiled binary you shared, but unfortunately that also didn’t work on my setup — in fact, with the binary, the screen stays completely black (even the backlight doesn’t turn on).
To rule out hardware issues, I tested the display using example code with TFT_eSPI, XPT2046, and LVGL, and both the screen and the resistive touch functionality are working perfectly. So I’m confident the hardware is fine.

I’m using:
ESP32-2432S028R, 2.8-inch resistive touchscreen, Resolution: 240x320

I’m happy to wait for your upcoming release, but if there’s anything I might be missing in the current setup — or if you have a different precompiled binary that might suit this exact model — I’d really appreciate your help. I’ve been working on this for a few days now without any luck.

Just for context: I’m also quite new to PlatformIO.

pranaysawarkar, 2025-05-27:
Hello Mitch,

Good news — I got the display working!

It turns out the issue was due to a mismatch in the display driver: the original code for the resistive CYD configuration was using the ST7789 driver, but my hardware is based on the ILI9341. After updating the panel setting in the hardware2432.cpp file to use the correct driver, the display came to life.

I did run into some issues with the screen and touch orientation, but I was able to resolve them by adjusting the cfg.offset_rotation parameter — now everything is displaying and responding correctly.

I’ve yet to connect it to the controller, but I’m confident the communication will work as expected.

Thank you again for your time and help — and for all the work you’ve put into FluidDial. Much appreciated!

Best regards,
Pranay

MitchBradley, 2025-05-31:
Fixed by https://github.com/bdring/FluidDial/commit/040918567adfb003f5f0b2486fd11d6d1fba8d8e and release v1.0.1

Closed 2025-05-31.

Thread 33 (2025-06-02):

Probing Scene Increments by 4

theoutfield, 2025-06-02:
This is a really neat project thanks for your hard work!

I started playing around with making a wireless MPG and I stumbled across this while researching.  I'm working with a grblHAL machine so I'm guessing I'm going to need to make a few changes here and there.   Since FluidNC and grblHAL are both cousins for GRBL I believe it's possible to get it working.  If anyone has tried it I would love to hear how it went.

I really want a wireless MPG because I've been using one with my Mach3 machine.  My plan is to modify this project to use ESP-NOW.  From what I've gathered in the code most of the changes need to be done in System.h and SystemArduino.cpp.  I have a BTT Scylla board with an ESP32 module on it for wireless communication.  My plan is to turn that into an ESP-NOW to UART bridge to communicate with the STM32H7.

I have the CYD and 100PPR encoder wheel.  In order to tryout the screen without connecting this to my CNC I just added a line to fool the display into thinking it was connected.

**FluidNCModel.cpp**
bool fnc_is_connected() {
    int now = milliseconds();
    //Added for testing Tony June 02
    **return true;**

I started messing around with the screens.  Most of them work great.  The probing screen was incrementing all values by 4 though.  I'm not sure if this is a bug or something setup for the M5Dial encoder.  After reviewing the code for the other screens I noticed most of them (all???) call the constructor with an encoder scaling of 4.  I modifed the code as shown below and everything worked afterwards.

**ProbingScene.cpp**
public:
    //Tony Modified June 2
    **ProbingScene() : Scene("Probe",4) {}**

MitchBradley, 2025-06-03:
The M5 Dial has detents every 4 pulses.  Actually it depends on how you configure the code that reads the encoder signals.  If you register a pulse on every phase transition, the detent is every 4 pulses.  If you configure it to register a pulse on a complete cycle of 4 phases, there is one pulse per detent.

FluidNC and grblHAL share the base GRBL line protocol, GCode parser, and motion planner, but have different solutions for extensions like how to handle extra input sources like files and alternative serial input channels.  "A few changes here and there" could turn into quite an effort.

theoutfield, 2025-06-03:
Thanks Mitch.  I didn't mean the few changes here and there as a simple task.  I was impressed with how well the code was done because I didn't have to jump all over the place looking where to find the communication functions.  grblHal does have a plugin "KeyPad" that enables KeyPad and or MPG I2C/UART port communication.  The ESP32 on the Scylla board is already connected to an STM32H7 UART so it should be doable.  The single character "realtime" commands are what I believe would require investigation.  grblHAL needs to see a 0X86?? code to enable the MPG and then I believe it will just relay the UART commands to the default parser.  If this is indeed true then the commands that the M5Dial is transmitting should work.  I'm going to give it a crack and see if it's within my abilities.  I'm sure there are more grblHal users than just myself who might find this useful.  I'm not partial to either grblHal or FluidNC.  The BTT Scylla board was very appealing so I'm working with what I have now.

The 100PPR encoder also has four counts per detent so the ProbingScene.cpp should be updated.  If you have the M5Dial you could verify it.

Tony

MitchBradley, 2025-06-04:
The xon/xoff flow control could be an issue. We use it to allow high speed communication without overrun, especially for stuff like sending large blocks of data like directory listings.

Another issue related to listings is the way we encapsulate such non-GRBL data in a JSON document that is further encapsulated in [... ] lines to conform to GRBL protocol rules

Helping GrblHAL users is not high on our list, especially if it results in extra support requests from people who are outside our ecosystem.

Some years ago I proposed coordinating on grbl protocol extensions and message formats, but Terje was not interested so I did not pursue it further.

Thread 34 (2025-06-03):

CYD Pendant communication problem with 6Axis PiBot Controller V4.7

pranaysawarkar, 2025-06-03:
Hello,

I’m currently working with the FluidNC firmware on a 6-Axis PiBot Controller V4.7 and would like to know if it’s possible to connect a pendant directly to the controller’s GPIO pins, without using the RJ11 expansion module.

My expansion module PCBs are still in production, so in the meantime I’m attempting to wire the pendant directly to available GPIOs on the controller. However, I haven’t had any success getting it to function correctly.

Could you please clarify whether direct GPIO connection is supported for the pendant interface, and if so, provide any guidance on the required pin mappings or configuration?

Thank you!

Cable Connection:
CYD GND : GND FluidNC
CYD 5v : + 5v FluidNC
CYD TX : io27
CYD RX : io25

YAML:
```
board: 6 Axis Universal CNC Controller
name: 6 Axis Universal CNC Controller
stepping:
  engine: I2S_STREAM
  idle_ms: 254
  pulse_us: 4
  dir_delay_us: 1
  disable_delay_us: 0

axes:
  shared_stepper_disable_pin: NO_PIN
  x:
    steps_per_mm: 40.000
    max_rate_mm_per_min: 400.000
    acceleration_mm_per_sec2: 25.000
    max_travel_mm: 300.000
    soft_limits: false
    homing:
      cycle: 2
      positive_direction: false
      mpos_mm: 150.000
      feed_mm_per_min: 100.000
      seek_mm_per_min: 200.000
      settle_ms: 500
      seek_scaler: 1.100
      feed_scaler: 1.100

    motor0:
      limit_neg_pin: gpio.2:low:pu
      limit_pos_pin: NO_PIN
      limit_all_pin: NO_PIN
      hard_limits: false
      pulloff_mm: 1.000
      standard_stepper:
        step_pin: I2SO.2
        direction_pin: I2SO.1
        disable_pin: I2SO.0

  y:
    steps_per_mm: 40.000
    max_rate_mm_per_min: 400.000
    acceleration_mm_per_sec2: 25.000
    max_travel_mm: 300.000
    soft_limits: false
    homing:
      cycle: 2
      positive_direction: true
      mpos_mm: 150.000
      feed_mm_per_min: 100.000
      seek_mm_per_min: 200.000
      settle_ms: 500
      seek_scaler: 1.100
      feed_scaler: 1.100

    motor0:
      limit_neg_pin: gpio.26:low:pu
      limit_pos_pin: NO_PIN
      limit_all_pin: NO_PIN
      hard_limits: false
      pulloff_mm: 1.000
      standard_stepper:
        step_pin: I2SO.5
        direction_pin: I2SO.4
        disable_pin: I2SO.7

  z:
    steps_per_mm: 400.000
    max_rate_mm_per_min: 200.000
    acceleration_mm_per_sec2: 25.000
    max_travel_mm: 300.000
    soft_limits: false
    homing:
      cycle: 1
      positive_direction: true
      mpos_mm: 150.000
      feed_mm_per_min: 100.000
      seek_mm_per_min: 800.000
      settle_ms: 500
      seek_scaler: 1.100
      feed_scaler: 1.100

    motor0:
      limit_neg_pin: gpio.33:low
      limit_pos_pin: NO_PIN
      limit_all_pin: NO_PIN
      hard_limits: false
      pulloff_mm: 1.000
      standard_stepper:
        step_pin: I2SO.10
        direction_pin: I2SO.9
        disable_pin: I2SO.8

i2so:
  bck_pin: gpio.22
  data_pin: gpio.21
  ws_pin: gpio.17

spi:
  miso_pin: gpio.19
  mosi_pin: gpio.23
  sck_pin: gpio.18

sdcard:
  card_detect_pin: NO_PIN
  cs_pin: gpio.5

probe:
  pin: gpio.39:low
  toolsetter_pin: gpio.36:low

# Using MOSFETs (Check Spindle Pin Usage
# coolant:
  # flood_pin: gpio.12
  # mist_pin: gpio.4
  # delay_ms: 0

start:
  must_home: false

# Begin Huanyang
uart1:
  txd_pin: gpio.15
  rxd_pin: gpio.16
  rts_pin: gpio.14
  baud: 9600
  mode: 8N1

Huanyang:
  uart_num: 1
  modbus_id: 1
  tool_num: 0
  speed_map: 0=0% 0=25% 6000=25% 24000=100%
  off_on_alarm: false

uart2:
  txd_pin: gpio.25
  rxd_pin: gpio.27
  rts_pin: NO_PIN
  cts_pin: NO_PIN
  baud: 1000000
  mode: 8N1

uart_channel2:
  report_interval_ms: 75
  uart_num: 2

# #begin PWM
# pwm:
  # pwm_hz: 5000
  # direction_pin: NO_PIN
  # output_pin: gpio.13
  # enable_pin: gpio.14
  # disable_with_s0: false
  # s0_with_disable: true
  # spinup_ms: 0
  # spindown_ms: 0
  # tool_num: 0
  # speed_map: 0=0.000% 10000=100.000%
  # off_on_alarm: false

# #begin Laser
# Laser:
  # pwm_hz: 5000
  # output_pin: gpio.4
  # enable_pin: gpio.12
  # disable_with_s0: false
  # s0_with_disable: true
  # tool_num: 1
  # speed_map: 0=0.000% 255=100.000%
  # off_on_alarm: true

# #begin 10V
# 10V:
  # forward_pin: gpio.15
  # reverse_pin: gpio.14
  # pwm_hz: 5000
  # output_pin: gpio.13
  # enable_pin: NO_PIN
  # direction_pin: NO_PIN
  # disable_with_s0: false
  # s0_with_disable: true
  # spinup_ms: 0
  # spindown_ms: 0
  # tool_num: 0
  # speed_map: 0=0.000% 1000=0.000% 24000=100.000%
  # off_on_alarm: false
```

Closed 2025-06-03.

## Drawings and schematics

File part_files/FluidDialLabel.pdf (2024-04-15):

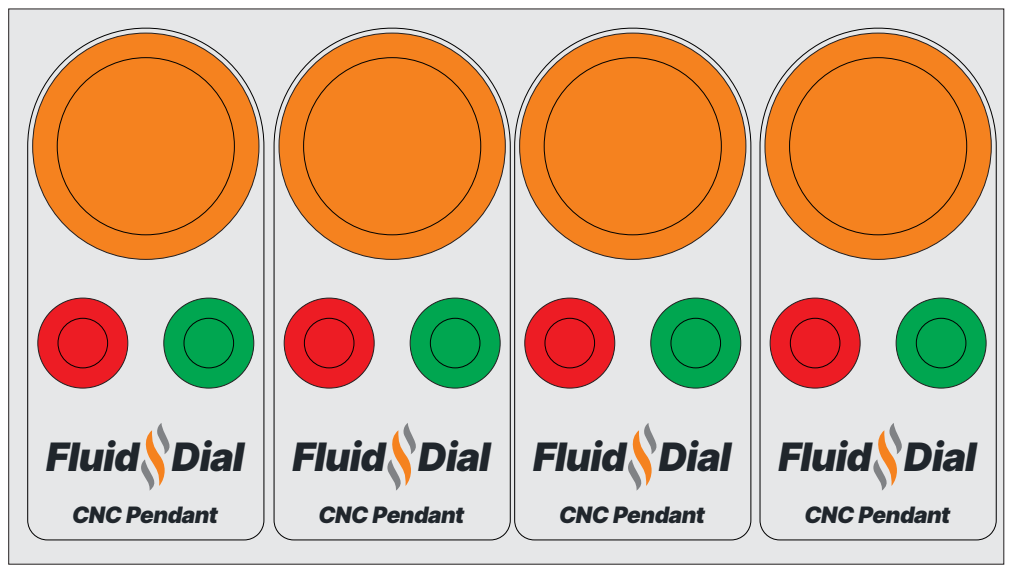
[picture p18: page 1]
Fluid Dial; CNC Pendant

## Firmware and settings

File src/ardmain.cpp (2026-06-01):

// Copyright (c) 2023 -	Barton Dring
// Use of this source code is governed by a GPLv3 license that can be found in the LICENSE file.

#include "System.h"
#include "FileParser.h"
#include "FluidNCModel.h"  // pendant_wait_for_fluidnc_ready()
#include "Scene.h"
#include "AboutScene.h"
#if defined(USE_M5) || defined(USE_LOVYANGFX)
#    include "BrightnessScene.h"
#endif

#ifdef USE_WIFI
#    include "WiFiConnection.h"
#    include "WiFiSetupScene.h"
#    include "PeerLink.h"
#    include "ESPNowPairingScene.h"
#    include "OTAScene.h"
extern Scene firstBootScene;
static bool _wifi_initialized  = false;
static bool _first_boot_active = false;
static bool _ota_boot_mode     = false;  // booted into the dedicated OTA-only loop
#endif

extern void base_display();
extern void show_logo();
extern "C" bool fnc_rx_waiting();

extern const char* git_info;

extern AboutScene aboutScene;

#ifdef USE_WIFI
extern Scene menuScene;
extern WiFiSetupScene wifiSetupScene;

void first_boot_complete() {
    _first_boot_active = false;

    TransportMode transport = wifi_get_transport();
    if (transport == TransportMode::UART) {
        fnc_realtime(StatusReport);
        activate_scene(&menuScene);
    } else if (transport == TransportMode::ESPNOW) {
        if (!_wifi_initialized) {
            _wifi_initialized = true;
            espnow_init();
        }
        activate_scene(&espnowPairingScene, &firstBootScene);
    } else {
        activate_scene(&wifiSetupScene);
    }
}
#endif

void setup() {
    init_system();

#if defined(USE_M5) || defined(USE_LOVYANGFX)
    display.setBrightness(brightnessScene.getBrightness());
#else
    display.setBrightness(aboutScene.getBrightness());
#endif

    show_logo();
    delay_ms(1000);  // view the logo and wait for the debug port to connect

    base_display();

    dbg_printf("FluidNC Pendant %s\n", git_info);

#ifdef USE_WIFI
    if (wifi_ota_boot_requested()) {
        _ota_boot_mode = true;
        dbg_println("Booting into OTA update mode");
        activate_scene(&otaScene);
        return;
    }
#endif

#ifndef USE_WIFI
    // Bounded boot probe — discards stale bootloader noise, asks FluidNC
    // for a status report, waits up to 7 s for any RX byte. If it times
    // out the runtime recovery ladder in fnc_is_connected() takes over.
    pendant_wait_for_fluidnc_ready(7000);
#else
    if (wifi_use_uart_mode()) {
        pendant_wait_for_fluidnc_ready(7000);
    }
#endif

    extern Scene* initMenus();
    Scene* menu = initMenus();

#ifdef USE_WIFI
    if (wifi_use_espnow_mode() && !_wifi_initialized) {
        _wifi_initialized = true;
        espnow_init();
    }
#endif

    // For debugging certain views without setting WiFi/UART transports
#if defined(DEV_SKIP_TO_ESPNOW_PAIRING) && defined(USE_WIFI)
    activate_scene(&espnowPairingScene);
#elif defined(DEV_SKIP_TO_SCENE)
    extern Scene DEV_SKIP_TO_SCENE;
    activate_scene(&DEV_SKIP_TO_SCENE);
#elif defined(USE_WIFI)
    // On first boot (no transport mode saved yet) show the setup wizard
    // immediately — before the main menu — so the user is never silently
    // dropped into WiFi mode.  first_boot_complete() handles the
    // transition once the user picks a transport.
    if (wifi_is_first_boot()) {
        _first_boot_active = true;
        activate_scene(&firstBootScene);
    } else if (wifi_use_espnow_mode() && !espnow_has_saved_pairing()) {
        activate_scene(&espnowPairingScene, &wifiSetupScene);
    } else if (!wifi_use_uart_mode() && !wifi_use_espnow_mode()
               && !wifi_load_config().valid) {
        // WiFi mode selected but no credentials configured yet.
        // Land in WiFiSetupScene; wifi_init() (deferred to loop) will
        // auto-start AP so the user can set credentials via browser.
        activate_scene(&wifiSetupScene);
    } else {
        activate_scene(menu);
    }
#else
    activate_scene(menu);
#endif
}

void loop() {
#ifdef USE_WIFI
    if (_ota_boot_mode) {
        // Drive the OTA state machine
        wifi_poll();
        dispatch_events();
        service_redisplay();
        return;
    }
    if (!_first_boot_active) {
        if (!_wifi_initialized) {
            // Defer transport init until after setup() returned + 1st render is
            // complete — ensures sprite caches allocate before WiFi/ESP-NOW consumes heap.
            _wifi_initialized = true;
            if (wifi_use_espnow_mode()) {
                espnow_init();
            } else {
                wifi_init();
            }
        }
        if (wifi_use_espnow_mode()) {
            espnow_poll();
        } else {
            wifi_poll();
        }
    }
#endif
    // fnc_poll() drains ONE byte per call. The WiFi transport can refill its
    // ring buffer with hundreds of bytes per loop iteration (a kernel TCP
    // window worth — preferences.json bursts in ~5 KB). Drain a chunk per
    // tick so the ring buffer can't overflow and silently drop bytes,
    // which corrupts the streaming JSON parser mid-document.
    //
    // Drain all pending data, but stop when RX is empty to avoid 
    // unnecessary Wi-Fi polling and reduce idle-loop jitter that can make small jog movements choppy.
    for (int i = 0; i < 64; i++) {
        fnc_poll();
        if (!fnc_rx_waiting()) {
            break;
        }
    }
    dispatch_events();  // Handle dial, touch, buttons
    service_redisplay();
}

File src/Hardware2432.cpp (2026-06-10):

// Copyright (c) 2023 Mitch Bradley
// Use of this source code is governed by a GPLv3 license that can be found in the LICENSE file.

// System interface routines for the Arduino framework

#include "System.h"

#define LGFX_USE_V1
#include <LovyanGFX.hpp>
#include <driver/i2c.h>

#include "Hardware2432.hpp"
#include "Drawing.h"
#include "NVS.h"
#include "Scene.h"

#include <driver/uart.h>
#include "hal/uart_hal.h"

#ifdef USE_WIFI
#    include "WiFiConnection.h"
#endif

// This pin is connected to a photoresistor that is ostensibly used
// for ambient light sensing.  It is possible to repurpose it as a UI
// lock by connecting a normally-open switch between the photoresistor
// and 3V3. Some people use the pushbutton switch on the side of the
// CYD that is supposed to control battery charging, cutting the
// traces that connect it to the battery circuit and running a wire
// over to the photoresistor.
#ifdef PIBOT_PENDANT
// PiBot uses GPIO 34 for the band switch, not a lockout input.
int lockout_pin = -1;
#else
int lockout_pin = GPIO_NUM_34;
#endif

#ifdef CYD_BATTERY_ADC
#    ifndef CYD_BATTERY_ADC_PIN
#        define CYD_BATTERY_ADC_PIN GPIO_NUM_39
#    endif
#    ifndef CYD_BATTERY_ADC_MULTIPLIER_NUM
#        define CYD_BATTERY_ADC_MULTIPLIER_NUM 1534
#    endif
#    ifndef CYD_BATTERY_ADC_MULTIPLIER_DEN
#        define CYD_BATTERY_ADC_MULTIPLIER_DEN 1000
#    endif
#endif

m5::Touch_Class  xtouch;
m5::Touch_Class& touch = xtouch;

static uint32_t read_panel_reg(lgfx::IBus* bus, int32_t pin_cs, uint_fast16_t cmd, uint8_t dummy_bits, uint8_t real_reads) {
    size_t        dlen     = 8;
    uint_fast16_t read_cmd = cmd;

    lgfx::pinMode(pin_cs, lgfx::pin_mode_t::output);

    bus->beginTransaction();

    // Dummy clocks with CS- high in hopes of clearing out any junk
    // It is unclear whether this is necessary, but it probably doesn't hurt
    lgfx::gpio_hi(pin_cs);
    bus->writeCommand(0, dlen);
    bus->wait();

    // printf("cmd:%02x", read_cmd);
    lgfx::gpio_lo(pin_cs);
    bus->writeCommand(read_cmd, dlen);
    bus->beginRead(dummy_bits);
    uint32_t res = 0;
    for (size_t i = 0; i < real_reads; ++i) {
        auto data = bus->readData(dlen);
        // printf(" %02x", data);
        res += ((data >> (dlen - 8)) & 0xFF) << (i * 8);
    }
    bus->endTransaction();
    lgfx::gpio_hi(pin_cs);

    // printf(" res %08x\n", (unsigned int)res);
    return res;
}

// xdisplay is an instance of the concrete wrapper class "LGFX" with knowledge
// of various details of the panel and touch
LGFX_Device  xdisplay;
LGFX_Device& display = xdisplay;

LGFX_Sprite canvas(&display);

uint8_t base_rotation = 2;

lgfx::Bus_SPI bus;
static void   init_bus() {
      auto cfg       = bus.config();
      cfg.freq_write = 55000000;
      cfg.freq_read  = 16000000;
      cfg.use_lock   = true;

      cfg.dma_channel = SPI_DMA_CH_AUTO;
      cfg.spi_host    = HSPI_HOST;
      cfg.pin_mosi    = GPIO_NUM_13;
      cfg.pin_miso    = GPIO_NUM_12;
      cfg.pin_sclk    = GPIO_NUM_14;
      cfg.pin_dc      = GPIO_NUM_2;
      cfg.spi_mode    = 0;
      cfg.spi_3wire   = false;

      bus.config(cfg);
      bus.init();
}

lgfx::Light_PWM light;

void init_light() {
    auto cfg        = light.config();
    cfg.pin_bl      = GPIO_NUM_21;
    cfg.freq        = 12000;
    cfg.pwm_channel = 7;
    cfg.offset      = 0;
    cfg.invert      = false;
    light.config(cfg);
}

void setBacklightPin(uint8_t pinnum) {
    auto cfg   = light.config();
    cfg.pin_bl = pinnum;
    light.config(cfg);
    light.init(255);
}

lgfx::Panel_ST7789  _panel_st7789;
lgfx::Panel_ILI9341 _panel_ili9341;

static void init_panel_st7789() {
    base_rotation = 0;

    auto& p = _panel_st7789;
    p.bus(&bus);

    auto cfg            = p.config();
    cfg.pin_cs          = GPIO_NUM_15;
    cfg.offset_rotation = base_rotation;
    cfg.bus_shared      = false;
#ifdef PIBOT_PENDANT
    cfg.invert = true;
#endif
    p.config(cfg);

    p.light(&light);

    display.setPanel(&p);
}

static void init_panel_ili9341() {
    base_rotation = 2;

    auto& p = _panel_ili9341;
    p.bus(&bus);

    auto cfg            = p.config();
    cfg.pin_cs          = GPIO_NUM_15;
    cfg.offset_rotation = base_rotation;
    cfg.bus_shared      = false;
#ifdef PIBOT_PENDANT
    cfg.invert = true;
#endif
    p.config(cfg);

    p.light(&light);

    display.setPanel(&p);
}

#ifdef DEBUG_TO_USB
Stream& debugPort = Serial;
#endif

int red_button_pin   = -1;
int dial_button_pin  = -1;
int green_button_pin = -1;

int enc_a, enc_b;

#ifdef CAPACITIVE_CYD
#    ifdef PIBOT_PENDANT
lgfx::Touch_FT5x06 _touch_ft5x06;
#    else
lgfx::Touch_CST816S _touch_cst816s;
#    endif
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

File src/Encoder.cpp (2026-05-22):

#include "Encoder.h"

#ifdef ARDUINO
#    include <Arduino.h>
#endif

#ifndef USE_LOVYANGFX
#    include "sdkconfig.h"
#    include "driver/pcnt.h"
#endif
#include "driver/gpio.h"

namespace {
#ifdef USE_LOVYANGFX
static const DRAM_ATTR int8_t quadrature_lut[16] = {
    0, -1, 1, 0,
    1, 0, 0, -1,
    -1, 0, 0, 1,
    0, 1, -1, 0,
};

static int               encoder_a_pin         = -1;
static int               encoder_b_pin         = -1;
static volatile int32_t  encoder_count         = 0;
static volatile uint8_t  encoder_state         = 0;
static volatile uint32_t encoder_last_event_us = 0;

static uint8_t IRAM_ATTR read_encoder_state_isr() {
    return (digitalRead(encoder_a_pin) << 1) | digitalRead(encoder_b_pin);
}

static void IRAM_ATTR encoder_isr() {
    uint8_t next_state = read_encoder_state_isr();
    int8_t  step       = quadrature_lut[(encoder_state << 2) | next_state];
    if (step) {
        encoder_count += step;
        encoder_last_event_us = micros();
    }
    encoder_state = next_state;
}
#else
bool pcnt_ready = false;
#endif
}

#ifndef USE_LOVYANGFX
/* clang-format: off */
void init_encoder(int a_pin, int b_pin) {
    pcnt_config_t enc_config = {
        .pulse_gpio_num = a_pin,  //Rotary Encoder Chan A
        .ctrl_gpio_num  = b_pin,  //Rotary Encoder Chan B

        .lctrl_mode = PCNT_MODE_KEEP,     // Rising A on HIGH B = CW Step
        .hctrl_mode = PCNT_MODE_REVERSE,  // Rising A on LOW B = CCW Step
        .pos_mode   = PCNT_COUNT_INC,     // Count Only On Rising-Edges
        .neg_mode   = PCNT_COUNT_DEC,     // Discard Falling-Edge

        .counter_h_lim = INT16_MAX,
        .counter_l_lim = INT16_MIN,

        .unit    = PCNT_UNIT_0,
        .channel = PCNT_CHANNEL_0,
    };
    if (pcnt_unit_config(&enc_config) != ESP_OK) {
        printf("PCNT init failed on encoder A pin %d\n", a_pin);
        return;
    }

    enc_config.pulse_gpio_num = b_pin;
    enc_config.ctrl_gpio_num  = a_pin;
    enc_config.channel        = PCNT_CHANNEL_1;
    enc_config.pos_mode       = PCNT_COUNT_DEC;  //Count Only On Falling-Edges
    enc_config.neg_mode       = PCNT_COUNT_INC;  // Discard Rising-Edge
    if (pcnt_unit_config(&enc_config) != ESP_OK) {
        printf("PCNT init failed on encoder B pin %d\n", b_pin);
        return;
    }

    pcnt_set_filter_value(PCNT_UNIT_0, 250);  // Filter Runt Pulses

    pcnt_filter_enable(PCNT_UNIT_0);

    gpio_pullup_en((gpio_num_t)a_pin);
    gpio_pullup_en((gpio_num_t)b_pin);

    pcnt_counter_pause(PCNT_UNIT_0);  // Initial PCNT init
    pcnt_counter_clear(PCNT_UNIT_0);
    pcnt_counter_resume(PCNT_UNIT_0);
    pcnt_ready = true;
}

int16_t get_encoder() {
    if (!pcnt_ready) {
        return 0;
    }
    int16_t count;
    pcnt_get_counter_value(PCNT_UNIT_0, &count);
    return count;
}

uint32_t encoder_event_us() {
    // PCNT has no per-pulse ISR; fall back to call time.
    return micros();
}
#else
void init_encoder(int a_pin, int b_pin) {
    encoder_a_pin = a_pin;
    encoder_b_pin = b_pin;

    pinMode(encoder_a_pin, INPUT_PULLUP);
    pinMode(encoder_b_pin, INPUT_PULLUP);

    encoder_count = 0;
    encoder_state = read_encoder_state_isr();

    attachInterrupt(digitalPinToInterrupt(encoder_a_pin), encoder_isr, CHANGE);
    attachInterrupt(digitalPinToInterrupt(encoder_b_pin), encoder_isr, CHANGE);
}

int16_t get_encoder() {
    return (int16_t)encoder_count;
}

uint32_t encoder_event_us() {
    return encoder_last_event_us;
}
#endif

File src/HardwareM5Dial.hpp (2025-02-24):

constexpr static const int ENC_A           = GPIO_NUM_40;
constexpr static const int ENC_B           = GPIO_NUM_41;
constexpr static const int DIAL_BUTTON_PIN = GPIO_NUM_42;

#include "M5Dial.h"

constexpr static const int FNC_UART_NUM = 1;
#ifdef UART_ON_PORT_B
constexpr static const int RED_BUTTON_PIN    = GPIO_NUM_13;
constexpr static const int GREEN_BUTTON_PIN  = GPIO_NUM_15;
constexpr static const int PND_RX_FNC_TX_PIN = GPIO_NUM_1;
constexpr static const int PND_TX_FNC_RX_PIN = GPIO_NUM_2;

#else  // UART is on PORT A
// This pin assignment avoids a problem whereby touch will not work
// if the pendant is powered independently of the FluidNC controller
// and the pendant is power-cycled while the FluidNC controller is on.
// The problem is caused by back-powering of the 3V3 rail through the
// M5Stamp's Rx pin.  When RX is on GPIO1, 3V3 from the FluidNC Tx line
// causes the M5Stamp 3V3 rail to float at 1.35V, which in turn prevents
// the touch chip from starting properly after full power is applied.
// The touch function then does not work.
// When RX is on GPIO15, the back-powering drives the 3V3 rail only to
// 0.3V and everything starts correctly.
constexpr static const int RED_BUTTON_PIN    = GPIO_NUM_1;
constexpr static const int GREEN_BUTTON_PIN  = GPIO_NUM_2;
constexpr static const int PND_RX_FNC_TX_PIN = GPIO_NUM_15;
constexpr static const int PND_TX_FNC_RX_PIN = GPIO_NUM_13;
#endif

#define WAKEUP_GPIO RED_BUTTON_PIN

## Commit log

2024-04-15 Don't track the autogenerated src/version.cpp
2024-05-04 Spindle override (#5)
    * Spindle override & save brightness
    * Added realtime Feed/Speed display.
    ---------
2024-05-23 More portable code that also supports 2432r028 "Cheap Yellow Display" (#7)
    * Spindle override (#5)
    * Fix macro problem due to missing /
    * Move some init code around for ortability
    * clang-format everything
    * jogbg.png has tranparency around the circle for the Windows version
    * Use safer version of json-streaming-parser
    * Fix reentrancy problem with FileParser
    It caused crashes after multiple refreshes of the macro list
    * Cleaner factoring of NVS support for Windows
    Instead of duplicating the prefs code, I implemented
    Windo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
    [CYD_Dial_Bottom.stl, CYD_Dial_Top.stl]
2024-06-11 Updates for homing and door.
2024-07-11 Scroll file preview (#9)
    Windows surrogates for the nvs_get/set routines.
    * F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
    [Hardware2432.cpp, HardwareM5Dial.cpp]
2024-12-14 Removed power menu
2024-12-21 Test branch for better buttons
2024-12-31 New button design
2025-02-11 Support capacitive CYD JC2432W328
2025-02-24 Revised pinout for capacitive CYD
2025-02-24 Reinstated DEBUG_TO_USB in the cyd build env.
    The alternative wiring that uses the same UART pins as for USB
    still needs to be tested to see if the CH340 chip conflicts with
    the Tx pin.
2025-02-28 Alternative Capacitive CYD wirings
2025-02-28 Add 3D files for JC2432W328C (#21)
    The current STL files pose several problems for the capacitive card:
    - USB port is not facing the hole
    - SD card port is offset
    - RBG LED interferes with screen placement
    The attached files are in STEP format which allows:
    - Printing (or not) the fixing holes
    - Selecting the location of the RJ12 port (top or bottom)
    - The possibility of having locations to install magnets (pause during printing at 12mm)
    - A multi-color printing of the logo
    I took the opportunity to correct a few small errors and add features:
    - hole in the top case slightly too small
    - problem in opening the RJ12 port
    - possibility of using M3 screws with nuts to close the case
    - Adding a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
    [CYD_Dial_JC2432W328C.FCStd, CYD_Dial_JC2432W328C_bottom.step, CYD_Dial_JC2432W328C_top.step]
2025-03-10 Update 3D Files for JC2432W328C (#22)
    * - 3 additional button integrations
    - Change from STEP to 3MF to be compatible with the Cura slicer
    - Possibility to use a rotary encoder instead of the CNC handwheel
    Attention: I have not tested it yet. I receive the components next week. I will update if necessary once tested.
    * Update parts after test
    [CYD_Dial_JC2432W328C.FCStd, CYD_Dial_JC2432W328C_bottom.3mf, CYD_Dial_JC2432W328C_bottom.step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]
2025-04-03 int/int32_t/long int conversions have to be explicit (#26)
    Without this patch you get compilation errors on Linux with pio 6.1
    [Scene.cpp]
2025-04-15 Fixed a system dependency that broke the Windows build
    [Drawing.cpp]
2025-05-17 Use explicit CYD board configurations instead of autodetect
2025-05-25 Combined build for all CYD board variants
2025-05-26 Fixed CYD panel selection code; both boards use ST7789
    [Hardware2432.cpp]
2025-05-29 Removed current/ intermediate directory in release/
2025-06-08 Fixes to locking feature
    1. In locked state, encoder motion is ignored instead of queued up
    2. Locking is present in the standard build. If you don't want to
    use it, don't wire up the button.
    3. Fixed some problems with screen redraw when switching layouts
    [Hardware2432.cpp, Scene.cpp]
2025-06-08 Corrected a comment; no functional change
    [Hardware2432.cpp]
2025-06-27 Enable switch buttons for resistive CYD
2025-08-11 layout_num and display_num are int32_t to prevent compile errors
    [Hardware2432.cpp]
2026-01-05 Menu drawing speed optimizations (#36)
    * Optimized the main menu drawing speeds by orders of magnitude. Tested several different approach, but memory contrains forced a lower sprite blending quality, resulting in new png buttons set that 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
    * For completeness if trying v2 of ImageButton::show
    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
2026-04-12 First working prototype - WiFi established
2026-04-12 Fix homing screen broken on prior WiFi addition commit
2026-04-12 Fix jog stalls/choppy jogging caused by overloading jogging buffer - Jogging is smooth now
    [Scene.cpp]
2026-04-12 Fix SD card files & macros retrieval
    [FluidNCModel.cpp]
2026-04-12 Add modal to confirm soft resets
    [StatusScene.cpp]
2026-04-12 Clear alarm upon soft-resetting
    [StatusScene.cpp]
2026-04-12 Add option to switch between UART and WiFi modes
2026-04-12 Improve Wifi/Uart selection layout: WIP
2026-04-12 Add button primitive and start improving UI
2026-04-12 Hide buttons on first boot scene as they are not used
2026-04-12 Change drawing method for buttons
2026-04-12 Fix glitch in back button of AP mode scene
2026-04-12 Deprecate exit button on AP mode view and remove extra back button on display orientation view
2026-04-13 Improve jog scene background drawing & add a build flag to debug individual scenes while skipping UART & WiFi initialization
    [ardmain.cpp]
2026-04-13 Fix MacOS M5 simulator
    [HardwareM5Dial.cpp]
2026-04-13 Skip to scene build flag defined in platformio file
    [ardmain.cpp]
2026-04-13 Add missing return that prevented status scene from showing during alarm
    [FluidNCModel.cpp]
2026-04-13 Eliminate the need to restart the pendant after WiFi/UART mode selection on initial boot
2026-04-13 Add missing num_layouts, layout_num, and redrawButtons stubs for M5Dial
    [HardwareM5Dial.cpp]
2026-04-13 Check for (and discard) non-JSON messages that interrupt an in-progress accumulation when parsing files
2026-04-19 Begin work on bringing back restart/reset buttons & make MacOS M5 simulator more functional
2026-04-19 Fix initial AP mode exit button loop; add touch & improve layout in SystemScene
2026-04-20 - Replace Display orientation with Brightness in M5 SystemScene (orientation is fixed on M5 Dial)
    [ardmain.cpp]
2026-05-16 Add battery level indicator for battery-powered M5 dial pendants
2026-05-19 Coalesce display redraws to avoid heap fragmentation under transport load
    Parser and WiFi callbacks (show_error, show_alarm, show_gcode_modes,
    set_axis_homed, handle_radio_mode, ConfigItem parsing, WiFi connect
    events, etc.) run inside fnc_poll / wifi_poll. Calling
    current_scene->reDisplay() directly from there redraws the screen on
    every incoming message, which on the menu scene decodes 7+ PNGs and
    fragments the LGFX/pngle allocator. Over WiFi this OOMs the mDNS
    responder within a minute; over UART it produces continuous flicker.
    Introduce request_redisplay() (sets a dirty flag) and
    service_redisplay() (rate-limited dispatch using UPDATE_RATE_MS, called
    once per main loop tick). Multiple p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
    [FluidNCModel.cpp, Scene.cpp, ardmain.cpp]
2026-05-19 Add bounded boot handshake, escalating link recovery, and BootLog diagnostics
    Boot flow: pendant_wait_for_fluidnc_ready() drains stale RX, then sends
    XON + StatusReport probes until FluidNC responds, with a 7 s budget. If
    the budget expires, the runtime recovery ladder in fnc_is_connected()
    takes over.
    Recovery ladder: a counter of consecutive disconnect_interval_ms
    timeouts without RX drives recover_link(). Ticks 1-2 drain stale bytes
    and re-send a status request; tick 3 calls reinit_fnc_uart() to fully
    reinstall the UART driver. In WiFi mode the driver re-init is skipped
    because the WiFi transport handles its own reconnection elsewhere.
    connect_init() now calls resetFlowControl() on the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
    [FluidNCModel.cpp, Hardware2432.cpp, HardwareM5Dial.cpp]
2026-05-19 Drop per-chunk 0xB2 realtime ack from handle_json
    handle_json() emitted a 0xB2 realtime byte at the end of every JSON
    chunk. Over Telnet this fills the TCP send buffer (EAGAIN) and
    eventually trips SO_SNDTIMEO / EHOSTUNREACH, stalling macro and file
    loads or tearing the WebSocket down. On UART it's harmless but
    pointless — FluidNC's \$File/SendJSON protocol doesn't require it.
2026-05-19 Replace WebSocket transport with raw TCP Telnet
    The WebSocket transport that landed in WiFi-Version PR #49 connects to
    FluidNC's HTTP port (ws://host:80/) and was rejected by FluidNC at
    TCP-connect time (errno 104 ECONNRESET). FluidNC ships a Telnet server
    on port 23 out of the box; the pendant doesn't need WS framing,
    multiplexing, or the HTTP upgrade dance.
    Swap WiFiConnection.cpp's implementation:
    - Drop the WebSocketsClient dependency (lib_deps in platformio.ini)
    and the #include <WebSocketsClient.h>.
    - Open a raw lwip TCP socket to FLUIDNC_TELNET_PORT (23) once WiFi STA
    associates and FluidNC's IP is resolved. Apply TCP_NODELAY,
    SO_SNDTIMEO 2s, and SO_KEEPALIVE 10/3/3 so dead pe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
    [Drawing.cpp, FirstBootScene.cpp, ardmain.cpp]
2026-05-19 Resolve *.local hostnames via mdns_query_a, bypassing unicast DNS
    WiFi.hostByName() tries unicast DNS before mDNS. On networks where the
    upstream resolver returns something for .local queries — a hijacking
    router, a stale cache entry on another host, the macbook itself
    answering its own Bonjour broadcast — this yields a confidently wrong
    address and the pendant tries to open Telnet against the wrong host.
    For hostnames ending in .local, go straight to ESP-IDF's mdns_query_a
    (multicast, 2 s timeout). Non-.local names still go through
    WiFi.hostByName as before.
    Requires mdns to be initialised before dnsResolveTask runs;
    MDNS.begin("fluiddial") in wifi_poll() already does that on the WiFi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
2026-05-19 Stream JSON chunks with brace-depth tracking instead of accumulating
    FluidNC returns large file/macro JSON listings as a sequence of
    line-terminated fragments, not a single message. The existing
    receive_plain_json() approach accumulated the whole document into a
    std::string before dispatching to handle_json(); for a long macro list
    this fragments the heap (every chunk grows the string + frees the old
    backing buffer), and any router-side TCP delay between chunks can
    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
2026-05-19 Advance macro chain when FluidNC returns bare error:N
    When the pendant fetches macros over Telnet it requests macrocfg.json
    first, then preferences.json on failure. FluidNC's UART path replies
    with a JSON-wrapped error so the streaming parser's endDocument fires
    and try_next_macro_file() runs naturally. The Telnet path replies with
    a bare "error:N" line — no JSON wrapper — so endDocument never fires
    and the listener chain stalls forever on "Reading Macros".
    Track which file request is in flight via s_pending_file_listener (set
    in request_macro_list_wu2/wu3, cleared in try_next_macro_file). Add an
    extern-C hook file_request_failed_advance() that show_error() in
    FluidNCModel calls; when a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
    [FluidNCModel.cpp]
2026-05-19 Add FNC_RX_TRACE diagnostic logging for the FluidNC link
    When something goes wrong on the wire — Telnet returning bare error:N
    instead of a JSON-wrapped status, a JSON document arriving split across
    chunks, the macro chain advancing unexpectedly — there was no way to
    see what was actually happening short of attaching a wireshark.
    Add dbg_printf traces gated on a single Config.h define:
    [rx-err] error:N
    [rx-ok]
    [rx-other] <line> — non-JSON / non-$ replies
    [json] len=N d=<depth> | <first 60 chars>
    [prefs] L<level> key=<key> — preferences-listener keys
    [macro-chain] start | macrocfg miss — chain transitions
    [macro-chain] preferenc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
    [FluidNCModel.cpp]
2026-05-19 Stop dropping RX bytes by bounding tcp_refill_rx + draining N per loop
    The Telnet RX path had two flow-control mismatches that together silently
    corrupted any FluidNC response larger than the ring buffer:
    1. wifi_poll/tcp_refill_rx kept calling recv() until the kernel TCP buffer
    was empty, pushing every byte into a 2 KB ring buffer via rx_push().
    rx_push() drops on overflow with no signal to the caller.
    2. The main loop called fnc_poll() exactly once per iteration, and
    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
2026-05-19 Add PiBot Pendant V4 hardware support
    - Hardware2432.hpp: UART0 on GPIO 1/3 when PIBOT_PENDANT is defined.
    - Hardware2432.cpp: FT5x06 capacitive touch on I2C_NUM_1 (SDA=32,
    SCL=25, INT=36), display invert on ST7789 and ILI9341 panels,
    encoder B on GPIO 27, dial/green button pins on 16/17, lockout_pin
    disabled.
    - platformio.ini: pull per-developer settings from platformio.local.ini;
    move upload_port/speed/flags out of [env:pibot] into the local file.
    - .gitignore: exclude platformio.local.ini.
    [Hardware2432.cpp, Hardware2432.hpp]
2026-05-21 Add battery indicator support for CYD
2026-05-21 Fix CYD encoder sensitivity in SystemScene and DisplaySettingsScene. Set encoder_scale=4 to match other navigation scenes, and switch the USE_LOVYANGFX encoder path from polling to interrupt-driven d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
    [Encoder.cpp]
2026-05-21 Improve debouncing of physical buttons
2026-05-21 Bring back brightness scene + retrieve stored value at boot. Fix UI lockout functionality
    [Hardware2432.cpp, ardmain.cpp]
2026-05-22 Fix button issue in resistive CYD
    [Hardware2432.cpp, Scene.cpp]
2026-05-22 Assign green button to rotate screen orientation.
2026-05-24 Refactor battery level calculation and improve WiFi scanning logic to prevent memory leaks
    [Drawing.cpp, Hardware2432.cpp]
2026-05-30 Revert physical switch debounce logic
    [Hardware2432.cpp]
2026-05-30 Default to ones position for M5, and tenths position for CYD due to larger number of pulses generated by encoder handwheels
2026-05-30 Revert breaking changes to resistive CYD button touch detection
    [Scene.cpp]
2026-05-31 Improve jogging over Telnet and ESP-NOW + gracefully teardown Telnet on mode switch or restart
2026-06-01 Disable battery indicator for M5 dial as it does not expose the necessary circuitry + clarify that WAKE/M5 must be held in order to wake from sleep
2026-06-01 Allow selecting connection mode in FirstBootScene by turning the encoder + Show version in boot screen under FluidDial Logo
2026-06-01 Drive OTA state machine to prevent hanging when starting an OTA session after credentials have been saved
    [ardmain.cpp]
2026-06-01 Replace short commit SHA for GrblParser dep with its long form to prevent build errors in new Platformio versions
2026-06-01 Pin espressif32 platform to official 6.9.0
2026-06-02 Attempt to fix resistive CYD buttons and enhance OTA update webpage with full changelog since current version
    [Hardware2432.cpp]
2026-06-08 Improve ESP-NOW pairing flow and minor ESP-NOW layout adjustments to Machines scene
2026-06-08 Fix missing Z-axis homing data by serializing and retrying ESP-NOW config queries
    [Scene.cpp]
2026-06-10 Fix PiBot Pendant V4 touch by disabling FT5x06 interrupt on GPIO 36
    GPIO 36 is an RTC GPIO without internal pull-up, causing unstable
    edge interrupts and occasional I2C corruption with the FT5x06
    touch controller on PiBot Pendant V4. Using polling mode (pin_int=-1)
    eliminates the touch-induced reboots and coordinate jumping.
    Impact: minimal. The non-PiBot capacitive touch configuration already
    uses pin_int=-1, confirming polling is a reliable choice.
    [Hardware2432.cpp]
2026-10-20 Open the selected main menu item with the green button
    On the main menu the green button did nothing, so opening a scene meant
    either pressing the dial or reaching for the touch screen. Every other
    menu-like scene already treats green as "select".
    Make the green button invoke the highlighted item, exactly as the dial
    button does. Disabled items (e.g. while disconnected) are still ignored.
